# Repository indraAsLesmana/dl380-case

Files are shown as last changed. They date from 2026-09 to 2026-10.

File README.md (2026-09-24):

# DL380 Case — desktop enclosure for an HP ProLiant DL380 G6/G7 8-bay 2.5" SFF drive cage

Parametric [FreeCAD](https://www.freecad.org/) Python model of an external desktop
enclosure that turns a salvaged **HP ProLiant DL380 G6/G7 8-bay 2.5" SFF drive cage
with backplane** (cage assy P/N 496074-001 and relatives) into a standalone,
fan-cooled JBOD-style box with its own internal **PicoPSU**.

Everything — body, lid and PicoPSU strap — is generated from one script. Change a
number at the top, re-run, get a new STEP file. The rear section height is derived
from the fan, so swapping fan size re-shapes the enclosure by itself.

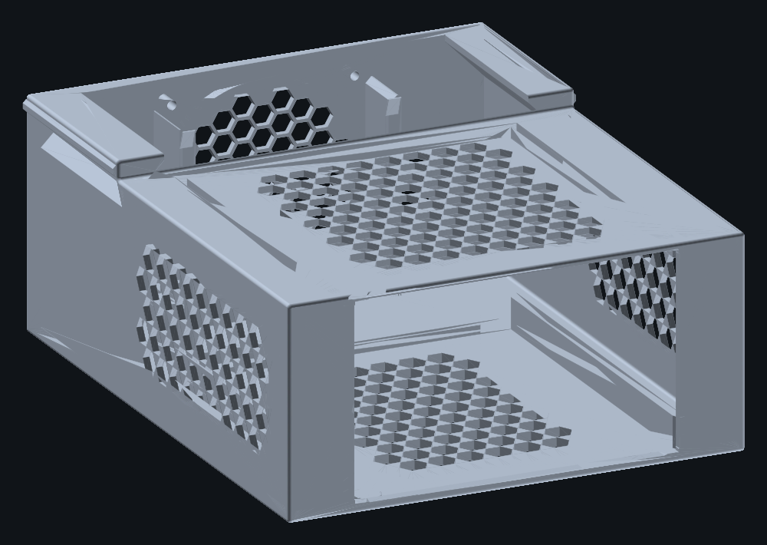
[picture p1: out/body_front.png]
front

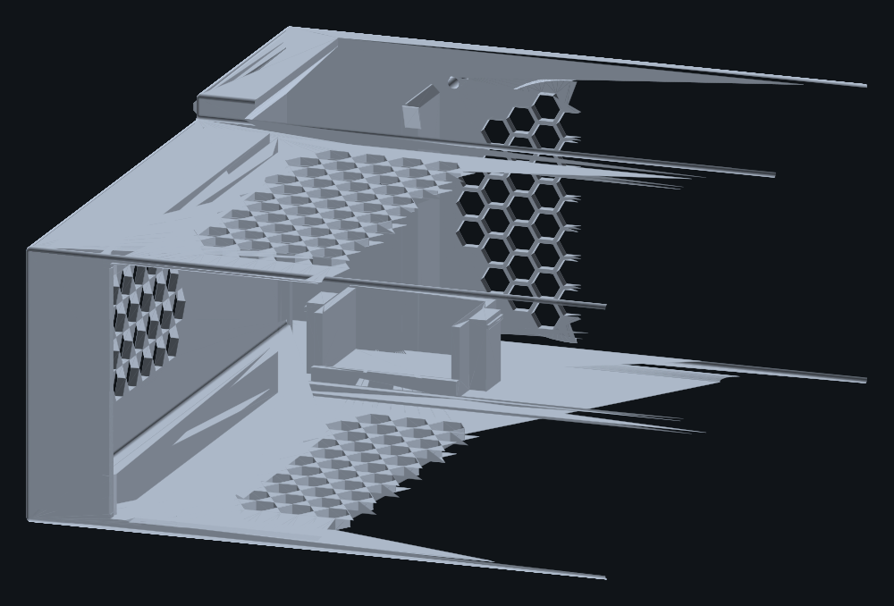
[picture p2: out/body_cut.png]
cutaway

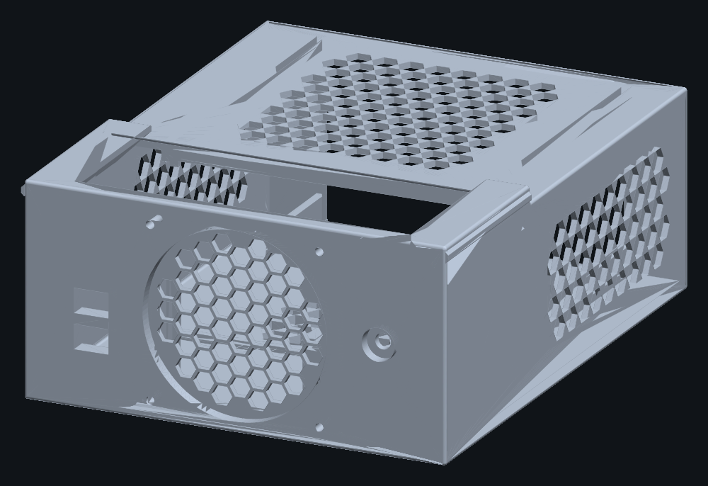
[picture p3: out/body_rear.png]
rear


**Building it? → [INSTALL.md](INSTALL.md)** — step-by-step assembly, including how
the drive cage goes in and the order the internals have to be fitted.

---

## Status

| | |
|---|---|
| Shell | `freecadcmd dl380_cage_case.py` builds and exports clean, no errors |
| Body solid | valid ✓ closed ✓ **208.40 × 102.80 × 253.40 mm** (572,008 mm³) — uniform 205.6 mm width & honeycomb net motif |
| Lid solid | valid ✓ closed ✓ **211.70 × 13.00 × 112.80 mm** (65,819 mm³) — slide-and-click with front pull ring |
| Strap solid | valid ✓ closed ✓ **69.20 × 10.00 × 14.00 mm** (4,267 mm³) — snap-fit |
| **Enclosure footprint** | **Uniform width**: 205.6 mm outer width throughout (bay & plenum), unbroken side walls; **253.4 mm depth** |
| **Drive bay net motif** | **258 hexagonal honeycomb cutouts (11 mm cell, 1.8 mm web)** on top, bottom, left & right walls — saves ~107 g solid (~80 g printed) |
| **Cage slide rails** | **Internal bottom slider rails (14 mm tall)** & **top guide ribs (5 mm tall)** with 1.5 mm lead-in chamfers |
| **Cable clearance** | **27.1 mm lateral space** to the left of the cage for side-facing 10-pin power plug & Wago blocks |
| **Lid retention** | **horizontal slide-and-click with front pull ring holder & compliant latch — 0 screws** |
| **PSU retention** | **toolless snap-fit strap with dual undercut retention teeth — 0 screws** |
| **Fan housing** | **Full-height 86 mm U-channel with front retaining rails (25.10 mm track depth)** — snug press-fit feel with zero screws |
| Body ↔ lid interference | **0.0000 mm³** (0.25 mm sliding clearance on 45° self-supporting rails) |
| Body ↔ strap interference | **0.0000 mm³** (0.20 mm snap clearance) |
| Cage slide path interference | **0.0000 mm³** (entrance to stop frame at Z = 162.0 mm) → CLEAR |
| PicoPSU phantom fit in the cradle | 0.0000 mm³ interference → CLEAR (transverse cradle shifted left X=-40.0 mm) |
| Build volume (Bambu Lab H2S / X1C) | **all parts fit on single 340×320 mm plate** (`print/dl380-case_all-parts.stl`, 331.2 × 253.4 mm layout) |
| Estimated print cost | **Rp 366,957 (~Rp 367,000)** for total enclosure at Rp 600/g PETG (612 g printed / 815 g solid) |
| Edge treatment | **every outer edge rounded** — body R1.4, lid R1.0, strap R1.4 |
| All parts printable | **100% support-free in native print orientations** ✓ |
| **Re-probed on the exported STEP** | `freecadcmd verify_step.py` → **71 probes, 0 failures** ✓ |

Reports: [`out/dl380_cage_case_report.txt`](out/dl380_cage_case_report.txt) is
written by the build; `verify_step.py` re-reads the exported STEP and probes the
body and the lid separately, with 71 probes confirming all geometries and clearances.

---

## Target hardware

The cage this was designed around, photographed on the bench:

| Photo | What it shows |
|---|---|
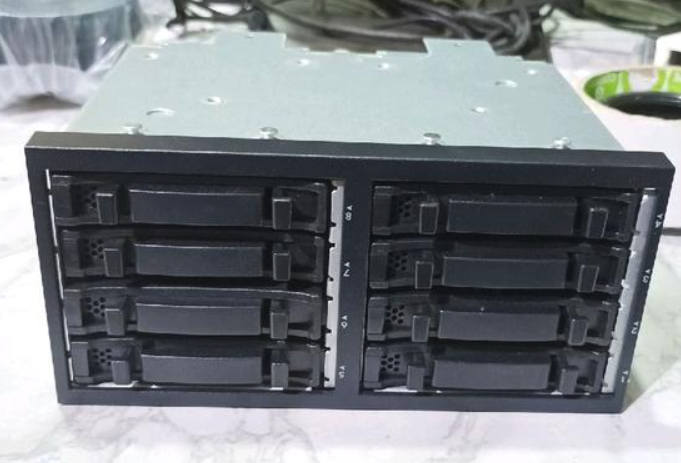
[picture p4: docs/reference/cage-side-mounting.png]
side
|  | Stamped steel cage, side/top mounting holes |
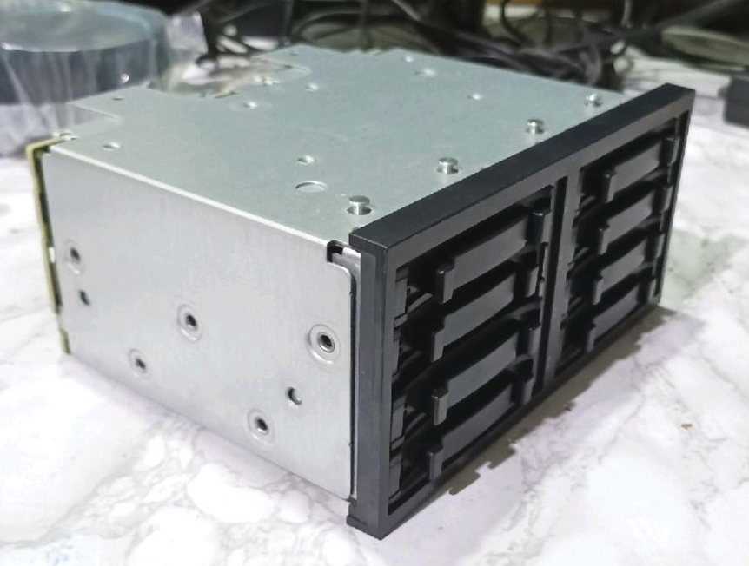
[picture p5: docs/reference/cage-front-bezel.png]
front
|  | Black plastic front bezel, 8 × 2.5" caddy slots |
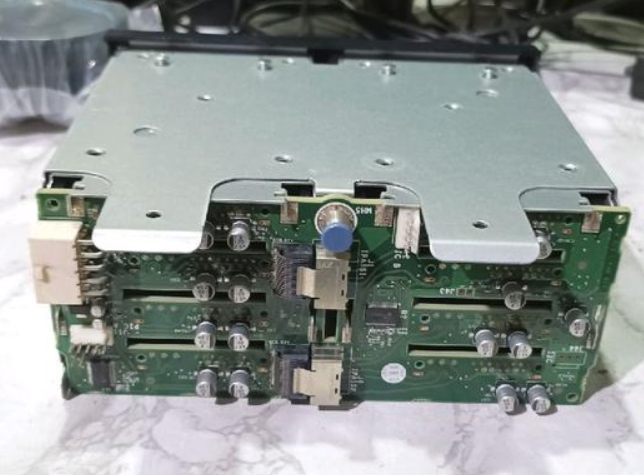
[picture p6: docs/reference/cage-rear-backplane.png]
backplane
|  | Backplane PCBs, left-facing 10-pin power socket, and top mounting rail |

Nominal cage envelope used for the model: **145.0 × 87.0 × 165.0 mm (W × H × D)**.

---

## Design

```
 z=0                                                               z=253.4
 | <---------- 165 bay ---------->|<-12->|<-- cradle -->|<-10.4->|<-25 fan->|<-8.4->|
 +================================+======+==============+========+==========+=======+ y=102.8
 | ^                              | boot |  PicoPSU     | cable  |   fan    |grille | STEP
 | |                              |      |  transverse  | space  |  INSIDE  | O90   | UP
 | | UNIFORM WIDE BODY (205.6 mm) |      |  X=+40 mm    |        |   92     | honey |
 | |                              |      |              |        |   frame  | comb  |
 | | [bottom rails + top ribs]    |      | [] |--board| |        |          |       |
 | |  capturing 145 mm cage       |      | [] | 44x31 | |        |  O86     |       |
 | | ### rear stop frame ###      |      |    |       | |        |  field   |       | y=0
 | v                              |      |    |-------| |        |          |       |
 +================================+======+==============+========+==========+=======+ y=94.6
 <------------------------------ 205.6 mm UNIFORM OUTER WIDTH ---------------------->
                                  <--------- 80 plenum ----------> (rear face)
   [] = strap bosses          all of the cradle and fan sits INSIDE the case
```

### Sections

**Bay (z 0 → 165)** — uniform outer width **205.6 mm** (matching the plenum for a clean,
monolithic profile with continuous side walls) and outer height 94.6 mm.
- **Front aperture**: 145.8 × 87.8 mm framed by 29.9 mm solid front cheeks on each side. The HP 2.5" SFF caddies and latch/eject levers slide straight in through the aperture, seating flush against the front face and sealing the front so that 100% of the exhaust fan's suction is pulled through the drive bays without bypass.
- **Internal slider rails**: 14 mm tall bottom guide rails on the floor and 5 mm tall ceiling ribs align and securely guide the 145 mm wide HP cage. A 1.5 mm 45° entry chamfer ensures the cage starts effortlessly.
- **Right wiring chamber**: Between the floor rails and ceiling ribs, a full **27.1 mm lateral clearance** on the right ($X = +72.9 \to +100.0\text{ mm}$) provides open routing space for the backplane's side-facing 10-pin power plug and harness.
- **Rear stop frame**: A 3 mm deep internal stop frame at $Z = 162 \to 165\text{ mm}$ sets the cage insertion depth; an inner aperture of 137.8 × 79.8 mm with a clearance notch on the lower-right edge ($X = +68.9 \to +72.9\text{ mm}$, $Y = 4 \to 50\text{ mm}$) guarantees zero fouling with the bottom-right backplane power port while leaving the left pillar solid from top to bottom.

**Plenum (z 165 → 245)** — **80 mm deep and 200 mm internal (205.6 mm outer)**.
The wide plenum gives **27.1 mm of lateral clearance** to the right of the backplane PCB,
providing ample room to plug in the 10-pin connector on the bottom right and execute a smooth bend toward the Wago lever blocks.
Laid out front to back:

| Z | What |
|---|---|
| 165 → 177 | 12 mm of clear boot space behind the backplane |
| 177 → 209.6 | the transverse PicoPSU cradle (shifted left to X = -40.0 mm) |
| 209.6 → 220 | 10.4 mm cable routing lane between cradle and fan |
| 220 → 245 | the fan, in its drop-in slot against the inside of the rear wall |

Shifting the PicoPSU to the left leaves a massive **117.2 mm of unobstructed plenum floor
on the right (X = -17.2 to +100.0 mm)** for the backplane power harness and three Wago 221
lever blocks.

**Fan — full-height U-channel housing with front retaining rails (snug press-fit feel).**
The ARCTIC P9 **slides straight down into a captive U-channel track** from the top and
seats on the plenum floor, exhausting straight through the grille. Nothing hangs off the
back of the enclosure and the blades are protected.

| | |
|---|---|
| Track | Z 219.90 → 245.00, providing an exact **25.10 mm track depth** for the 25.0 mm fan frame |
| Seat | the plenum floor (Y = 4.0 mm) — sets the height so screw holes line up if bolted |
| Sides (X) | two tall guide rails extending up to Y = 90.0 mm (`FAN_GUIDE_H = 86.0 mm`), 0.15 mm clearance per side, 2.5 mm lead-in chamfer |
| Forward (Z-) | **two tall front retaining rails** (Z 217.0 → 219.9 mm) overlapping the frame outer rim by 2.5 mm per side with top entry chamfers; completely clears the Ø86 mm blade circle |
| Behind (Z+) | the solid rear wall / grille face |
| Up (Y+) | **two fins on the lid's underside** reach down to 1 mm above the frame's top edge |

The full-height U-channel wraps the fan on all four vertical corners, providing a positive,
snug press-fit feel without requiring screws or rattling. With the lid closed, the fan is
completely locked in place in all 6 degrees of freedom.

Because the fan seats on the floor, its axis sits at **y = 50** rather than the
plenum's centre at 52, and the grille pocket and all four mounting holes moved down
2 mm with it.

**Drive bay net motif — weight & cost reduction cutouts.**
Instead of heavy solid plastic slabs around the drive bay, the top roof, bottom floor,
and left/right side walls feature an architectural **hexagonal honeycomb net motif**:
- **Geometry**: 258 hexagonal cells, **11.0 mm across flats** with **1.8 mm webs** (equivalent to 4–5 passes of a standard 0.4 mm nozzle for maximum rigidity and clean toolpaths).
- **Four-panel coverage**:
  - Top roof: 93 cells across a 120 × 134 mm field.
  - Bottom floor: 71 cells across a 90 × 122 mm field (clearing the rubber foot recesses).
  - Left and right side walls: 47 cells each across 134 × 68 mm fields.
- **Structural margins**: Solid perimeter borders are preserved at the front mouth ($Z < 16\text{ mm}$), the rear stop frame ($Z > 150\text{ mm}$), and along the floor rails and ceiling guide ribs.
- **Cost impact**: Saves **107 g of solid PETG (~80 g printed)** per enclosure, reducing filament cost and print time while facilitating passive air circulation.

**Honeycomb exhaust grille** — punched through a **3 mm membrane** at the bottom of
a Ø90 × 5.4 mm counterbore in the outer face, not through the full 8.4 mm wall, so
it costs little airflow and the wall stays stiff enough to carry the fan inserts.
55 flat-top hexagonal cells, 9 mm across flats with 1.2 mm webs, **78 % open** across
the field. The cell field is inset from the pocket wall so no cell can break out of
it; the tightest edge margin, pocket to case top edge, is **7.80 mm**.

**Rear wall (z 245 → 253.4)** — **8.4 mm** thick (3 × wall). Carries the grille, the
four fan mounting holes, two cable slots and the DC jack.

**Cable egress — out of the back.** Two 17 × 12 mm rounded slots at X = −70,
Y = 33 and 50 take the two SFF-8087 → SFF-8088 leads. Separate slots so each cable
keeps its own strain relief instead of two cables sawing against each other in one
hole. 16.50 mm from the slot corners to the grille pocket, 24.30 mm outboard.

**DC input jack** — Ø8 through, counterbored Ø16 × 5 mm on the outer face at
(+70, 52). The counterbore leaves a **3.4 mm panel** for the jack's nut
instead of the full 8.4 mm wall. 24.80 mm outboard margin.

**PicoPSU cradle** — see below.

**Lid — a slide-and-click housing that needs no screws.** The body is one cohesive
print with a closed top over the drive bay; the plenum gets a separable lid that
**slides horizontally forward along +Z** into interlocking rails on the body's outer
walls and clicks shut with a compliant snap latch.

| | |
|---|---|
| Guide rails | 45° beveled guide rails on outer walls (`RAIL_W = 1.4 mm`, `RAIL_H = 2.4 mm`), completely support-free |
| Skirt runners | 45° inverted runner grooves inside the lid skirts with `0.25 mm` sliding clearance |
| Snap latch | 18 mm compliant cantilever latch on the front face engaging a `20 × 2.6 × 1.8 mm` recessed catch pocket on the front vertical step |
| Catch tooth | 1.2 mm ramped catch tooth (`LATCH_TOOTH_D = 1.2 mm`) with ergonomic thumb-release tab |
| Pull ring holder | **Ø14 mm circular finger ring** (24 mm outer width, 22 mm projection) at front center for effortless removal |
| Located by | 45° interlocking rails in X and Y, front vertical step in -Z, snap tooth in +Z |
| Retained fan | fan captured on 4 sides by body U-channel; lid underside is flush over the fan with 4.0 mm clearance |
| Removed by | hooking index finger into the front pull ring and sliding the lid backward |

**100% screwless and toolless.** The interlocking 45° rails prevent the lid from lifting
up (+Y) or pulling outward in ±X. The front vertical step stops it from sliding too far
forward (+Z), and the latch tooth locks into the catch pocket to prevent it from sliding
backward (-Z).

**Roof gussets** — two **18 mm 45° gussets** run the length of the plenum roof/wall
corners. They make the roof printable without supports and provide rigid backing for
the slide rails.

**Base** — four Ø12 × 2 mm recesses for rubber feet, in a 4 mm floor.

**Edge treatment** — every outer edge is rounded: **R1.4** on the body and the PSU
strap, **R1.0** on the lid. Nothing on the outside is a sharp edge.

The rounds are applied to the **bare shell**, before anything is cut into it.
Filleting the finished body would also try to round the 1.2 mm honeycomb webs and
every internal corner, which OCC will not survive; and the coplanar faces have to be
merged first, or the seams between the two shell boxes get filleted into grooves.

R1.4 is close to the ceiling here: every outer edge sits on either a 2.8 mm wall or
a 3 mm lid plate, and the round has to leave a printable rim behind it.

**The cost, stated plainly**: the outer corner round and the cage lead-in flare both
remove material from the same 2.8 mm front wall, and at the mouth corner they add
up. Keeping the original 1.6 mm flare would have left **0.5 mm** there, so the flare
is reduced to 0.8 mm, which leaves exactly **1.00 mm**. So the cage's lead-in is
half what it was — see [INSTALL.md](INSTALL.md) step 2 for what that means in
practice.

### Why the rear section steps up 8.2 mm

A **92 mm fan frame is taller than the 87.8 mm cage bore**, so it cannot sit inside a
case only as tall as the bay. The rear section therefore steps from 94.6 mm to
102.8 mm — an 8.2 mm step, not the 37 mm tower an earlier revision had.

This is derived, not hand-set:

```python
INT_H_PLEN = max(INT_H, FAN_SIZE + 2*FAN_INNER_CLEAR)
REAR_H     = FLOOR_T + INT_H_PLEN + WALL     # 102.8 with a 92 mm fan
```

Give it a fan of **83.8 mm or less** and `REAR_H` collapses back to `BAY_H` and the
top becomes a flat prism. `FAN_SIZE` and `FAN_INNER_CLEAR` are the only numbers you
touch.

---

## Fitted fan — ARCTIC P9 PWM PST (ACFAN00298A)

Figures from ARCTIC's own spec sheet (`Spec_Sheet_P9_PWM_PST_EN.pdf`), not from a
reseller listing.

| | |
|---|---|
| Frame | 92 × 92 × 25 mm, 106 g |
| Mounting hole pattern | **82.5 × 82.5 mm** — matches `FAN_PATTERN` |
| Speed | 200–3000 rpm, PWM controlled (0 rpm below 5 % duty) |
| Airflow | 38.83 cfm / 65.97 m³/h |
| Static pressure | 3.12 mmH₂O — a high-pressure fan, which is what a caddy-stacked backplane wants |
| Bearing | fluid dynamic |
| Electrical | 12 V DC, 0.12 A = **1.44 W**, starts at 5 V |
| Lead | 400 mm + 80 mm PST daisy-chain, 4-pin plug **and** 4-pin socket |
| Ambient | 0–40 °C, 6 year warranty |

**Fit inside the enclosure**

| | |
|---|---|
| Bore it sits in | 200.0 × 96.0 × 80.0 mm |
| Frame clearance | 2.0 mm on every side |
| Fan position | Z 220 → 245, flat against the rear wall |
| Grille field | Ø90 pocket, Ø~86 of actual honeycomb |
| Mounting holes | Ø4.2 at (±41.25, 50 ± 41.25) — optional, the housing holds it |
| Housing | slot at Z 220→245, 0.2 mm per side, lid fins 1 mm above the frame top |

**Mounting** — with the housing, mounting is just "lower it in". The four M3 × 30
positions are still cut into the rear wall (heat-set inserts pressed in from the
**outside** face) if you would rather bolt it, in which case the screws go in from
inside the plenum. Point the fan so it exhausts outward and check the moulded
airflow arrow.

**Fan lead** — the 4-pin plug never leaves the case now, so no wall notch is needed.
Route the lead forward along the plenum and tuck it down before the lid goes on.

---

## PicoPSU cradle

Sized from mini-box's own figures for the **picoPSU-120: 31 × 44 × 21 mm (1U)**,
57 g with its harness, DC input a 5.5 × 2.5 × 10 mm barrel.

The board is **oriented transversely (44 mm across X, 31 mm along Z)** and shifted
right to **X = +40.0 mm** on the plenum floor. This leaves **117.2 mm of unobstructed
plenum floor on the left (X = -100.0 to +17.2 mm)** for the backplane power harness and
Wago 221 lever blocks.

| | |
|---|---|
| Cradle bore | 45.6 (across X) × 32.6 (along Z) mm (0.8 mm clearance per side) |
| Cradle Z | 177.0 → 209.6 mm |
| Mouth to backplane face | **12 mm** — board stops 13.6 mm short even fully forward |
| Plinth | 3 mm, so the solder side never touches the floor |
| Front lip | 6 mm tall (3 mm above the plinth) — stops it sliding forward |
| Retaining strap | 67.2 × 4 × 14 mm snap-fit strap with dual undercut teeth |
| Retention ledges | 0.8 mm retention ridges on the corner bosses — **no screws, no inserts** |

The build runs a **phantom PicoPSU box** through the cradle and reports the
interference (0.0000 mm³ → CLEAR).

**Two things to check on your own wiring**

1. The cradle holds the *bare board*. If you mount the 24-pin ATX connector facing
   up, it stands taller than the 21 mm board and the strap will be in the way. Either
   fit the strap around it, or change `PSU_BORE_Z` to move the strap along the cradle.
2. There is no motherboard here, so a PicoPSU will not start on its own — **PS_ON#
   must be tied to ground** for it to run as a standalone 12 V → 5 V/3.3 V supply.
   The fan's 1.44 W is nothing for the Wago 221 terminals, so it can share them.

---

## BOM

| Item | Qty | Notes |
|---|---|---|
| Printed body | 1 | ≈ 648 cm³ / ≈ 823 g at 1.27 g/cm³ (solid) |
| Printed lid (slide-and-click) | 1 | ≈ 66 cm³ / ≈ 83 g |
| Printed PSU strap (snap-fit) | 1 | ≈ 4.3 cm³ / ≈ 5 g |
| **ARCTIC P9 PWM PST 92 mm** | 1 | inside the plenum, exhaust; 106 g |
| **PicoPSU-120** (or similar) | 1 | 31 × 44 × 21 mm; add a 12 V brick + panel DC jack |
| Panel-mount 5.5 × 2.5 mm DC jack | 1 | Ø8 body, ≤ 3.4 mm panel |
| Rubber feet Ø12 × 2 mm | 4 | in base recesses |
| SFF-8087 → SFF-8088 cables | 2 | exit through the rear slots |
| Wago 221 lever terminals | 3 | in the plenum |
| **Mandatory screws / inserts** | **0** | **100% toolless assembly** |
| *Optional: M3 × 6 heat-set inserts* | *4* | *only if bolting the fan for transport* |
| *Optional: M3 × 30 screws* | *4* | *only if bolting the fan for transport* |
| *Optional: M3 screws + nuts* | *2–4* | *only if pinning the cage through side holes* |

### Print settings & Kit

PETG or ASA suggested (the plenum sees warm server air). 0.2 mm layers, 3–4 walls,
4–5 top/bottom layers. Total printed mass is **612 g** (815 g solid upper bound).
With the drive bay honeycomb net motif, the enclosure saves **107 g of solid PETG (~80 g printed)**!

### Cost Estimation @ Rp 600 / gram (PETG)

| Part | Volume (cm³) | Solid Mass (g) | Printed Mass (g) | Cost (Rp 600/g) |
|---|---|---|---|---|
| **Body** | 572.0 | 726 | 545 | Rp 326,902 |
| **Lid** | 65.8 | 84 | 63 | Rp 37,615 |
| **PSU Strap** | 4.3 | 5 | 4 | Rp 2,439 |
| **TOTAL** | **642.1** | **815** | **612** | **Rp 366,957** (~Rp 367,000) |

**No supports needed for any part**:
- The **body** prints upright on its base with the front opening facing up.
- The **lid** prints top-plate face down on the bed with skirts pointing up; the 45° runner overhangs are self-supporting.
- The **strap** prints flat on the bed.

A pre-arranged print kit is provided in `print/`:
- `print/dl380-case_all-parts.stl` / `.obj`: all 3 parts arranged on a single **331.2 × 253.4 mm plate** (fits within a 340 × 320 mm Bambu Lab build volume).
- Individual STLs: `dl380-case_body.stl`, `dl380-case_lid.stl`, `dl380-case_psu-strap.stl`.

---

## Rebuilding and verifying

```bash
# generate STEP + STL + report into ./out
freecadcmd dl380_cage_case.py

# export print-ready kit (individual + all-parts plate) into ./print
freecadcmd export_print_kit.py

# re-probe the exported STEP: every opening open, every wall solid
freecadcmd verify_step.py

# optional: dependency-free preview renders (SVG -> PNG via rsvg-convert)
python3 render_stl.py out/dl380_cage_case_body.stl out/body.png
python3 render_stl.py out/dl380_cage_case_lid.stl out/lid.png
python3 render_stl.py out/dl380_cage_case_strap.stl out/strap.png
```

Tested with FreeCAD 1.1.3 (`freecadcmd`). The scripts also run from the FreeCAD GUI
Python console via `exec(open("dl380_cage_case.py").read())`.

---

## Parameters

All at the top of `dl380_cage_case.py`. Nothing derived is hand-edited.

| Parameter | Default | Meaning |
|---|---|---|
| `CAGE_W` / `CAGE_H` / `CAGE_D` | 145.0 / 87.0 / 165.0 | HP cage envelope |
| `FIT_CLEAR` | 0.4 | slide-in clearance, per side |
| `WALL` / `FLOOR_T` | 2.8 / 4.0 | wall and floor thickness |
| `FILLET_R` / `FILLET_R_LID` | 1.4 / 1.0 | outer edge rounds, body+strap / lid |
| `LEAD_IN` / `LEAD_DEPTH` | 0.8 / 4.0 | cage lead-in flare — capped by the rounds |
| `SLIDE_CLEAR` | 0.25 | sliding clearance between body rails and lid runners |
| `RAIL_W` / `RAIL_H` / `RAIL_YC` | 1.4 / 2.4 / 98.0 | 45° slide rail width, height, and Y centerline |
| `LATCH_W` / `LATCH_TOOTH_H` / `LATCH_TOOTH_D` | 18.0 / 2.0 / 1.2 | snap latch width, tooth height, and undercut depth |
| `LID_RING_W` / `LID_RING_LEN` / `LID_RING_HOLE` | 24.0 / 22.0 / 14.0 | front pull ring width, projection, and finger hole Ø |
| `PSU_SNAP_CLEAR` / `PSU_LEG_T` / `PSU_TOOTH_W` | 0.2 / 2.0 / 0.8 | snap-fit strap clearance, leg thickness, and retention tooth |
| `REAR_WALL_LAYERS` | 3 | rear wall in wall-units → 8.4 mm |
| `GUSSET_H` | 18.0 | 45° roof gusset size (sets the service opening width) |
| `PLENUM_D` | 80.0 | clear depth behind the backplane |
| `FAN_SIZE` / `FAN_INNER_CLEAR` | 92.0 / 2.0 | frame size and bore clearance |
| `FAN_APERTURE` / `FAN_PATTERN` / `FAN_HOLE` | 86.0 / 82.5 / 4.2 | grille field and mounting pattern |
| `FAN_INSET` | 25.0 | fan depth against the rear wall |
| `FAN_GUIDE_CLEAR` | 0.15 | clearance per side in the fan housing |
| `FAN_GUIDE_T` / `FAN_GUIDE_H` / `FAN_GUIDE_CHAM` | 3.0 / 86.0 / 2.5 | rail thickness, height, lead-in |
| `FAN_FRONT_Z_IN` / `FAN_FRONT_X_IN` | 219.90 / 43.50 | front retaining rail boundary (25.10 mm track depth) |
| `NET_CELL` / `NET_WEB` | 11.0 / 1.8 | drive bay honeycomb net cell and web size |
| `GRILLE_CELL` / `GRILLE_WEB` | 9.0 / 1.2 | rear exhaust grille honeycomb cell and web size |
| `GRILLE_RIM` / `GRILLE_DEPTH` | 2.0 / 3.0 | solid rim, membrane thickness |
| `PSU_W` / `PSU_L` / `PSU_H` | 31 / 44 / 21 | the board envelope |
| `PSU_CX` | 40.0 | cradle center offset along X (leaves 117 mm cable floor on left) |
| `PSU_CLEAR` / `PSU_BOOT` / `PSU_PLINTH_T` | 0.8 / 12.0 / 3.0 | fit, backplane gap, plinth |
| `PSU_WALL_H` / `PSU_FRONT_LIP` | 24.0 / 6.0 | cradle wall and lip heights |
| `PSU_BORE_Z` | 193.3 | strap position along the cradle |
| `REAR_CABLE_SLOT_*` | X −70, Y 33/50, 17 × 12 | rear cable egress |
| `DC_JACK_X` / `DC_JACK_Y` | 70.0 / 52.0 | DC jack position |
| `DC_JACK_DIA` / `DC_JACK_PAD` / `DC_JACK_DEPTH` | 8.0 / 16.0 / 5.0 | jack hole and counterbore |
| `CAGE_SCREW_Z` | 15…155 | candidate cage anchor positions |
| `REAR_H` | *derived* | follows the fan automatically |

---

## Caveats — read before printing

1. **Cage side-screw positions are unverified.** `CAGE_SCREW_Z` places six Ø3.4 holes
   per side wall as a *menu*, not a measurement — the real cage's own holes were not
   measured. The rear stop frame holds the cage regardless.
2. **The PicoPSU cradle is sized for the bare picoPSU-120 (31 × 44 × 21 mm).** Check
   your board before printing; other PicoPSU models differ, and `PSU_W/L/H` and
   `PSU_BORE_Z` are the numbers to change.
3. **The DC jack counterbore leaves a 3.4 mm panel.** Measure your jack's neck and
   change `DC_JACK_PAD` / `DC_JACK_DEPTH` if it wants something different.
4. **Rear section is 8.2 mm taller than the bay.** That is what an internal 92 mm fan
   costs. Use an 83.8 mm-or-smaller fan and the top is flat again.
5. **Dimensions are from the brief, not from calipers.** If your cage measures
   differently, change `CAGE_W` / `CAGE_H` / `CAGE_D` and rebuild.
7. **Nothing here has been printed yet.** The geometry is verified as valid, closed,
   non-interfering, phantom-fitted and feature-by-feature against the exported STEP,
   but that is not the same as a successful print.

---

## Repository layout

```
dl380_cage_case.py            parametric model -> STEP/STL (the thing to edit)
verify_step.py                re-probes the exported STEP; non-zero exit on failure
render_stl.py                 standalone STL -> shaded PNG renderer
docs/reference/               photos of the target hardware
out/
  dl380_cage_case.step        body + lid + strap, high precision  <- deliverable
  dl380_cage_case_body.step   body only
  dl380_cage_case_lid.step    lid only
  dl380_cage_case_strap.step  PicoPSU strap only
  dl380_cage_case_*.stl       print meshes
  dl380_cage_case_report.txt  derived dimensions + sanity checks
  *.png                       preview renders
```

---

## License

MIT — see [LICENSE](LICENSE).

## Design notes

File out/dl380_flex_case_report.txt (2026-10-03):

================================================================================
DL380 MODULAR 2-PIECE FLEX-ATX ENCLOSURE - BUILD & COMPARISON REPORT
================================================================================

Target Cage:      HP ProLiant DL380 G6/G7 8-bay 2.5" SFF (144.81 x 75.52 x 137.25 mm)
Target PSU:       Enhance ENP-2320 (Flex-ATX 200W, 150 x 81.5 x 40.5 mm)
Target Fan:       92 mm Arctic P9 PWM PST / Noctua NF-A9 (92 x 92 x 25 mm)

VARIANT 1: STANDARD (CAD Built-in DfAM Sacrificial Supports)
  Front Case Vol: 893,933.96 mm3 (isClosed: True) | Facets: 10,866
  Back Case Vol:  600,264.80 mm3 (isClosed: True) | Facets: 6,310
  Service Lid Vol:21,875.90 mm3 (isClosed: True) | Facets: 300
  Total Volume:   1,516,074.66 mm3 (1,516.1 cm3)

VARIANT 2: CLEAN (Zero CAD Supports - Ready for Slicer Auto-Support Comparison)
  Front Case Vol: 778,782.94 mm3 (isClosed: True) | Facets: 2,282
  Back Case Vol:  553,984.83 mm3 (isClosed: True) | Facets: 2,082
  Total Volume:   1,354,643.67 mm3 (1,354.6 cm3)
  CAD Support Material Delta: 161.4 cm3 (~203.4 g PETG)

================================================================================

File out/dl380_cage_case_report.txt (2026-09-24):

==============================================================================
 DL380 G6/G7 8x2.5" SFF drive-cage desktop enclosure - build report
==============================================================================

 TARGET HARDWARE
   cage outer              : 145.0 x 87.0 x 165.0 mm (W x H x D)
   sleeve bore             : 145.8 x 87.8 mm  (0.4 mm/side clearance)

 ENCLOSURE  (body)
   outside W x H x D       : 205.6 (uniform) x 102.8 x 253.4 mm
   bay section             : 205.6 (W) x 94.6 (H) x 165.0 (D) mm
   fan/plenum section      : 205.6 (W) x 102.8 (H) x 88.4 (D) mm
   top profile             : STEPPED - rear section is 8.2 mm taller than the bay (fan is inside)
   wall / floor / rear wall: 2.8 / 4.0 / 8.4 mm
   plenum clear depth      : 80.0 mm
   roof gussets            : 18.0 mm tall at 45 deg, carrying the lid rails

 HP CAGE SLIDER RAILS & GUIDE RIBS  (internal)
   bottom guide rails      : 14.0 mm tall x 4.0 mm thick on floor (Z 2.8..165.0)
   top guide ribs          : 5.0 mm tall x 4.0 mm thick on roof (Z 2.8..165.0)
   front mouth lead-in     : 1.5 mm 45 deg chamfer at entry (Z=2.8..5.8)
   lateral wiring clearance: 23.1 mm open side chamber on right for 10-pin harness

 FAN  -  ARCTIC P9 PWM PST  (ACFAN00298A)
   nominal size            : 92 x 92 x 25 mm, 106 g
   P9 PWM PST rating       : 200-3000 rpm PWM (0 rpm below 5%),
                             38.83 cfm | 65.97 m3/h, 3.12 mmH2O static,
                             0.12 A @ 12 V = 1.44 W, fluid dynamic bearing
   position                : in a slot against the rear wall, Z 220.0..245.0,
                             seated on the plenum floor
   fan axis                : (0, 50.0) - the frame sits ON the floor at
                             y=4.0, so the axis is 2.0 mm below the
                             centre of the plenum bore
   hole pattern            : 82.5 x 82.5 square, O4.2
   hole centres (X,Y)      : (+/-41.2, 8.8)  (+/-41.2, 91.2)

 FAN HOUSING  - tall U-channel with front retaining rail (press-fit feel)
   how it goes in          : straight DOWN into the U-channel at Z 220.0..245.0
   seat                    : the plenum floor.  This sets the height, so
                             the screw holes line up if you ever use them
   sides (X)               : two tall guide rails 86.0 mm up from the floor (y=90.0),
                             0.15 mm clearance per side, 2.5 mm lead-in
   behind (Z+)             : the rear wall / grille face at Z=245.0
   forward (Z-)            : two tall front retaining rails (Z=217.0..219.9),
                             overlapping fan frame by 2.5 mm per side with 2.5 mm entry chamfer
   track depth (Z)         : 25.10 mm (for 25.0 mm fan frame) -> snug press-fit feel
   up (Y+)                 : closed by lid plate (4.0 mm headroom above frame)
   => restrained on all six sides: toolless slide-in, zero screws, rock solid

 DRIVE BAY NET MOTIF  (weight & cost reduction cutouts)
   pattern                 : hexagonal honeycomb mesh (11.0 mm cells, 1.8 mm webs)
   cutout panels           : top roof, bottom floor, left wall, right wall
   total hex cells         : 258 cells
   cost impact             : reduces raw plastic mass by ~107 g solid (~80 g printed)

 HONEYCOMB EXHAUST GRILLE  (recessed into the outer face)
   pocket                  : O90.0, 5.4 mm deep
   membrane                : 3.0 mm thick
   cell / web              : 9.0 mm across flats / 1.2 mm walls
   cells                   : 55
   open fraction of field  : 78%
   tightest edge margin    : 7.80 mm (pocket to the top edge)

 PicoPSU CRADLE  (transverse, shifted left X=-40.0 mm)
   board                   : 44.0 (L, across X) x 31.0 (W, along Z) x 21.0 (H) mm
   cradle inner            : 45.6 x 32.6 mm, 0.8 mm clearance per side
   cradle Z                : 177.0 .. 209.6  (mouth to rear wall)
   backplane clearance     : 12.0 mm from the cradle mouth to the
                             backplane face - the board cannot reach it
   lateral clearance       : 117.2 mm open plenum floor on right (X=-17.2..100.0)
                             for backplane power cable and Wago 221 lever blocks
   plinth                  : 3.0 mm, board sits clear of the floor
   front lip               : 6.0 mm tall (3.0 mm above the plinth),
                             stops the board sliding forward
   retaining strap         : 67.2 x 4.0 x 14.0 mm, toolless snap fit
                             clips over corner boss ledges (0 screws, 0 inserts),
                             0.4 mm gap over the board top

 DC INPUT JACK  (rear wall)
   centre                  : (-70.0, 52.0)
   panel counterbore       : O16.0 x 5.0 mm deep, leaving a 3.4 mm
                             thick panel for the jack nut
   jack hole               : O8.0 through
   edge margin             : 164.80 mm outboard

 CABLE EGRESS  (rear wall, beside the grille)
   2 slots                : 17.0 (X) x 12.0 (Y) mm, rounded corners
   centres                 : X=+70.0   Y = 33.0, 50.0
   fitted SFF-8088 lead    : ~12.5 x 8 mm, so 4.5 x 4.0 mm of slack
   clearance to the grille : 16.50 mm (slot corner to the pocket)
   clearance to the edge   : 24.30 mm outboard

 SERVICE LID  (slide-and-click housing - 100% screwless)
   outside                 : 211.7 (W) x 90.8 (D) mm, 3.0 mm plate
   skirts                  : 10.0 mm deep at the sides, 6.4 mm
                             at the front (covering the step), all 2.8 mm thick
   guide rails             : 45 deg beveled slide rails on outer walls (Z 166.5..253.4)
                             glide clearance: 0.25 mm
   cantilever latch        : 18.0 mm wide spring arm with 1.2 mm catch tooth
   pull ring holder        : O14.0 mm finger hole at front center for effortless removal
   positive stop           : front face seats against 8.2 mm step at Z=165.0
   screws                  : 0 (100% toolless slide-and-click)

   FAN CABLE & RETENTION   - fan captive with no screws
   fan underside clearance : flush lid underside, fan captured in body U-channel
   headroom over the frame : 4.0 mm (frame top y=96.0, ceiling y=100.0)
   skirt vs the case       : the skirt is outside the case, so it cannot
                             reach any cable that is inside

   service opening         : 164.0 wide, Z 165.0..245.0, R12.0 corners
   entry for the fan       : Z 220.0..245.0, straight down into the housing.
                             The front tabs and rails make that the only
                             way in, so there is nothing to slide or align
   roof left beside opening: 18.0 mm each side, plus 0.0 mm across
                             the front

 EDGE TREATMENT  (outside edges only, for handling and to stop chipping)
   body / strap fillet     : R1.4 on every outer edge
   lid fillet              : R1.0 (its plate is only 3.0 mm thick)
   filleted                : yes
   material the rounds took : 941 mm3 off the bare shell
   wall at the mouth corner : 1.00 mm  (2.8 wall - R1.4 - 0.4 lead-in)
   lead-in flare           : 0.8 mm total, down from 1.6 mm - the round
                             and the flare both cut the same 2.8 mm
                             front wall, so one had to give

 VOLUME / MASS / PRICING @ Rp 600/g
   body   volume / solid / prn:   572.0 cm3 |   727 g (solid) |   545 g (printed) -> Rp    326926
   lid    volume / solid / prn:    65.8 cm3 |    84 g (solid) |    63 g (printed) -> Rp     37615
   strap  volume / solid / prn:     4.3 cm3 |     5 g (solid) |     4 g (printed) -> Rp      2439
   ----------------------------------------------------------------------------------
   TOTAL ENCLOSURE          :   642.1 cm3 |   816 g (solid) |   612 g (printed) -> Rp    366981

 SANITY CHECKS
   body valid              : True
   lid valid               : True
   strap valid             : True
   body closed (solid)     : True
   strap closed (solid)    : True
   body bbox               : 208.40 x 102.80 x 253.40
   lid  bbox               : 211.70 x 13.00 x 112.80
   body/lid interference    : 0.0000 mm3
   body/strap interference  : 0.0000 mm3
   build volume (Bambu H2S 340x320x340):
     body  fits            : True
     lid   fits            : True
     strap fits            : True
   PicoPSU phantom fit (board pushed to the rear of the cradle):
     board/body interference: 0.0000 mm3  -> CLEAR
     board front to backplane: 13.60 mm in the rearmost position
   HP cage slide path (145.0 x 87.0 mm, entrance to stop frame at Z=162.0):
     cage/body interference  : 0.0000 mm3  -> CLEAR
   slide rails on body     : length 86.9 mm (Z 166.5..253.4), height 95.4..100.6 mm
   front catch pocket      : 20.0 (W) x 2.6 (H) x 1.8 (D) mm at Z=165.0
   cable egress slots through the rear wall:
     X= +70.0 Y= 33.0 : 0% inside solid  -> CLEAR
     X= +70.0 Y= 50.0 : 0% inside solid  -> CLEAR

 NOTES
   * The 92 mm fan frame is taller than the 87.8 mm bay bore, so the
     rear section steps up 8.2 mm to hold it inside.
     The largest fan that would keep the top flat is 83.8 mm.
   * Air path: open front -> caddies -> plenum -> fan -> honeycomb grille.
     No tapered duct any more: with the fan inside the plenum there is
     nothing to funnel into, and the volume is needed for cabling.
   * The grille is punched through a 3.0 mm membrane, not the full 8.4 mm
     wall, so it costs little airflow and still looks clean.
   * Cage side-screw Z positions are a starting suggestion: drill/print
     only the pair that lines up with your cage's own holes.
   * Rear stop frame inner aperture: 137.8 x 79.8 mm
==============================================================================

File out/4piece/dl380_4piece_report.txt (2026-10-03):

================================================================================
DL380 4-PIECE MODULAR ENCLOSURE - BUILD REPORT
================================================================================

Part 01A (Lower Front): 173,420.24 mm3 (isClosed: True)
Part 01B (Upper Front): 634,305.48 mm3 (isClosed: True)
Part 02A (Lower Back):  109,494.95 mm3 (isClosed: True)
Part 02B (Upper Back):  427,795.79 mm3 (isClosed: True)
Part 03  (Service Lid): 21,891.54 mm3 (isClosed: True)
Part 04  (Cage Pin x1): 224.84 mm3 (isClosed: True)
Total Volume:           1,367,357.67 mm3 (1,367.4 cm3, ~1,722.9 g PETG)
================================================================================

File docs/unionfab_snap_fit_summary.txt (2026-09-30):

Title: Cached Content
Description: Fetched from cache
Source: https://www.unionfab.com/blog/2025/06/3d-print-snap-fit
---
Guide to 3D Printed Snap Fits +[Design Tips]
Guide to 3D Printed Snap Fits +[Design Tips]
Allen Yang
About
12
mins
Published:
June 4, 2025
Design tool-free 3D printed snap-fit joints for fast, durable assembly—explore TPU, Nylon, PETG, and expert FDM/SLS tips for real-world applications.
Introduction
What is a Snap-Fit?
A snap-fit is a type of mechanical joint that enables quick assembly and disassembly using elastic deformation. It eliminates the need for screws, adhesives, or other fasteners. Widely used in electronics, consumer products, and modular components, snap-fit joints are especially well-suited for 3D printing due to their cost-effectiveness and ease of fabrication.
Common Snap-Fit Types
Cantilever (Most Common, Single-Sided Insertion)
A single flexible arm that locks into place with a one-sided insertion. Subtypes include:
source: hp.com
Straight Cantilever:
A simple straight arm with a hook or tab at the end (e.g., used in food container lids for easy locking).
L-shaped Cantilever:
Features a right-angle bend, ideal for compact spaces (e.g., latches in electronics enclosures).
U-shaped Cantilever:
Two parallel arms forming a U-shape, offering balanced flexibility (e.g., in medical device casings).
Annular (Ring Structure)
Annular Snap Fit and Its Assembly Operation
Source: hp.com
A circular snap fit that uses radial flexibility (expansion/contraction) to lock, such as bottle caps, jar lids, or pipe fittings.
Torsional
Torsional Snap-fit and Its Assembly Operation
Source: hp.com
Engages through rotational deformation, requiring a twisting motion to lock (e.g., hose couplings or electrical plugs).
Latching
Snap Fit Plastic Push Latch
Source: pingood.com.tw
Two separate components (a hook and a slot) that interlock and can be manually unlocked, like safety harnesses or smartphone back covers.
Snap Fit Manufacturing Processes
Manufacturing Process
Suitability for Snap Fits
Description
3D Printing
Highly Suitable
Ideal for rapid prototyping, custom designs, and low-volume production. Enables quick design iteration with flexible materials like TPU/Nylon.
Injection Molding
Most Common
The standard for high-volume production, especially for plastic parts (e.g., electronics casings, toys). Offers cost efficiency at scale.
CNC Machining
Limited
Poorly suited for flexible components (metals/hard materials lack elasticity). Best for rigid prototypes with simple geometries.
Silicone Molding + Casting
Feasible for Low-Volume
Used to produce small batches of flexible snap fits (e.g., resin-cast clips) with moderate precision and flexibility.
Key Takeaway:
3D printing is the most versatile for snap fits, especially in early design stages. It allows rapid testing of locking mechanisms, easy modification of flexible arms/hooks, and supports materials that mimic production-grade elasticity.
3D Printing Processes for Snap Fits
1. Fused Deposition Modeling (FDM/FFF)
How it works:
Melts thermoplastic filaments (e.g., PLA, PETG, TPU) and deposits them layer by layer to build parts.
Why it’s ideal:
Flexibility: Supports elastic materials (e.g., TPU) for bendable cantilever arms or torsion springs.
Speed: Rapid turnaround for prototyping, allowing same-day design iterations.
Cost: Affordable for small batches or one-off custom designs.
2. Multi Jet Fusion (MJF) / Selective Laser Sintering (SLS)
How it works:
MJF: Fuses fine nylon powder (e.g., PA12, PA11) using a fusing agent and infrared energy.
SLS: Sintering nylon powder with a high-powered laser in a powder bed.
Why they’re ideal for snap fits:
Material Strength: Nylon parts have high tensile strength and fatigue resistance—ideal for repeated snap actions.
Elastic Recovery: PA11 and PA12 exhibit excellent shape memory, supporting tight tolerances without permanent deformation.
Isotropic Properties: Near-uniform strength in all directions—critical for flexible arms or latches.
No Support Structures: Enables printing of complex or nested snap geometries.
Surface Finish: MJF offers better detail and consistency; SLS is slightly rougher but similarly strong.
Want to bring your snap fit model to life? Choose Unionfab—your professional 3D printing partner for fast, reliable results from concept to production!
Sign Up to Get 10% Discount
Material Selection
Selecting the right material is critical to achieving durable, functional, and reusable snap-fit mechanisms. The ideal material must withstand stress concentrations, flex repeatedly without fatigue, and provide consistent shape recovery after deflection.
1. Key Material Requirements
Flexibility
The material should bend without cracking, especially in cantilever or living hinge designs where repeated deflection is expected.
Elastic Recovery
It must return to its original shape after deformation to ensure a secure, reusable snap-fit engagement.
Fatigue Resistance
The material should withstand repeated cycles of stress without permanent deformation or failure.
Layer Adhesion
In 3D printing, strong inter-layer bonding is crucial to prevent delamination, especially in parts subjected to flexing or bending.
Printability
Materials should offer good dimensional accuracy, surface quality, and consistency to meet tight snap-fit tolerances.
Impact Strength
Important for applications where snap-fits may experience sudden forces during assembly or in use.
2.  Recommended Materials for Snap-Fit Manufacturing
Material
Flexibility
Elastic Recovery
Fatigue Resistance
Layer Adhesion
Printability
Impact Strength
Nylon (PA12/11)
⭐
⭐
⭐
⭐
⭐
⭐
☆*
⭐
⭐
⭐
⭐
⭐
⭐
⭐
⭐
☆
⭐
⭐
☆
⭐
⭐
⭐
☆
PETG
⭐
⭐
☆
⭐
⭐
☆
⭐
⭐
☆
⭐
⭐
⭐
☆
⭐
⭐
⭐
☆
⭐
⭐
⭐
☆
ABS
⭐
⭐
☆
⭐
⭐
☆
⭐
⭐
☆
⭐
⭐
☆
⭐
⭐
☆
⭐
⭐
⭐
☆
PLA
⭐
☆
⭐
☆
⭐
☆
⭐
⭐
⭐
☆
⭐
⭐
⭐
⭐
⭐
⭐
⭐
☆
TPU
⭐
⭐
⭐
⭐
⭐
⭐
⭐
⭐
⭐
⭐
⭐
⭐
⭐
⭐
☆
⭐
⭐
⭐
☆
⭐
⭐
⭐
☆
⭐
⭐
⭐
☆
ASA
⭐
⭐
☆
⭐
⭐
☆
⭐
⭐
⭐
☆
⭐
⭐
⭐
☆
⭐
⭐
☆
⭐
⭐
⭐
☆
PC (Polycarbonate)
⭐
⭐
⭐
☆
⭐
⭐
⭐
☆
⭐
⭐
⭐
☆
⭐
⭐
☆
⭐
☆
⭐
⭐
⭐
⭐
⭐
*Note: ☆=1/2
⭐
3. Material Selection Tips by Use Case
Snap-fit components come in many forms, but they can all be grouped according to their functional scenarios. Below is a breakdown of typical snap-fit use cases, along with recommended 3D printing materials tailored to the performance requirements of each application.
High-cycle snap-fit clips
Recommended Materials: Nylon, TPU
Reason: Offer superior fatigue resistance and flexibility, enabling them to withstand frequent opening and closing operations without easily getting damaged.
General-purpose parts
Recommended Materials: PETG, ABS
Reason: Strike a good balance between durability and printability. They can meet the strength requirements of general usage scenarios while being easy to 3D print.
Outdoor use
Recommended Materials: ASA, PETG
Reason: Possess excellent UV and weather resistance, allowing them to be used outdoors for long periods without aging rapidly.
Prototyping / low-stress fits
Recommended Materials: PLA+, Tough PLA
Reason: Easy to print and have a fast printing speed, enabling the rapid production of prototypes. Suitable for assembly scenarios with low stress.
Flexible / soft interfaces
Recommended Material: TPU
Reason: Have high elasticity, providing a comfortable touch. Ideal for applications requiring soft and deformable interfaces.
Structural or heat-tolerant parts
Recommended Materials: PC, Nylon
Reason: Feature high strength and good thermal resistance, meeting the manufacturing requirements of parts with demands for structural strength and high-temperature tolerance.
Still unsure which material to choose? Talk to Unionfab experts to help you make final decisions.
Talk to Unionfab Experts
Snap-Fit Design Guidelines
Designing effective snap-fit components in 3D printing requires balancing flexibility, strength, and dimensional accuracy. This guide covers geometry considerations, and tolerance strategies to ensure durable and functional snap mechanisms.
Dimensions & Tolerances
These geometric rules help you design snap-fits that function reliably, even under repeated use and varying print conditions.
Clearance / Gap Tolerance
Recommended: 0.2–0.5 mm, depending on the printer's dimensional accuracy and material shrinkage.
Purpose: Prevents parts from fusing or being too tight.
Adjustment: For softer or more flexible materials (e.g., PETG, TPU), tighter clearances (~0.2 mm) may work. For stiffer materials or less accurate printers, go closer to 0.5 mm.
Arm Length
Rule of thumb: 2–3× the arm thickness.
Effect: Longer arms provide greater flexibility and easier snap engagement but may be more prone to fatigue. Shorter arms are stiffer but more durable.
Design Note: Keep a consistent cross-section and avoid sudden thickness changes to reduce stress concentration.
Hook Angle
Insertion Angle: 30°–45° recommended.
Explanation:
Lower angles (30°): Easier to insert, but weaker holding force.
Higher angles (45°+): Greater retention, but harder to engage or disengage.
Tip: Consider using asymmetrical hooks—shallow angle for insertion side, steeper on the locking side.
Fillets and Radii
Why: Sharp corners at the base of the snap arm act as stress risers and can lead to failure during flexing.
Suggestion:
Add fillets with radius = 0.5–1.0× arm thickness at the base of snap arms.
Smooth transitions between hook, arm, and base improve durability.
Lead-in Angles / Chamfers
Purpose: Chamfers or tapered entries guide the snap feature into place during assembly.
Angle Range: 20°–30° lead-in on hooks and mating surfaces is ideal.
Design Bonus: Improves user experience by reducing required insertion force and misalignment risk.
Undercuts & Retention Geometry
For strong locking, integrate subtle undercuts or stepped grooves—but avoid excessive interference which can cause cracking.
Use slicer preview to verify printability of undercut features or consider using breakaway supports if needed.
Material-Specific Notes
PLA: Brittle; suitable for one-time snaps or non-critical features.
PETG: Good balance of strength and flexibility; ideal for reusable snap-fits.
ABS/ASA: Tough, weather-resistant; great for functional outdoor parts.
Nylon: Excellent fatigue resistance; best choice for high-cycle snapping.
TPU: Highly flexible; useful for interference fits or soft latching mechanisms.
Testing & Iteration Tips
Prototype quickly using draft print settings to verify tolerances and clearances.
Print in intended orientation and test snap-fit behavior in real-world conditions.
Use modifier meshes to increase infill only in snap regions for strength without wasting material.
Printing Parameters & Orientation
Choosing the right print settings and orientation is crucial for strong, functional, and reliable snap-fit components. Below are detailed recommendations to help optimize strength, flexibility, and print quality.
Layer Height
Recommended: 0.1–0.2 mm
Why it matters:
Smaller layer heights (e.g., 0.1 mm) give finer detail and smoother surfaces, ideal for tight-fitting snap features.
Larger layer heights (e.g., 0.2 mm) print faster but may create rougher surfaces and weaker layer adhesion.
Tip:
For precision snap-fits or parts that require frequent engagement, use ≤ 0.15 mm for better dimensional accuracy.
Wall/Perimeter Thickness
Recommended: ≥ 1.2 mm (3 or more perimeters)
Why it matters:
Thicker walls increase strength in flexible arms and hook regions.
Critical for preventing cracks at stress points, especially in cantilever snap joints.
Tip:
Use 3–4 wall lines, or wall thickness = 3× nozzle diameter (e.g., 0.4 mm nozzle → 1.2 mm wall).
Printing Temperature
Why it matters:
Correct extrusion temperature ensures strong inter-layer adhesion. Too low = weak layers, too high = stringing or deformation.
Material
Nozzle Temp
Bed Temp
Notes
PLA
190–210°C
50–60°C
Keep cooling fan on for crisp detail
PETG
230–250°C
70–90°C
Reduce fan speed to strengthen layers
ABS
230–250°C
90–110°C
Enclosure recommended to reduce warping
ASA
240–260°C
90–110°C
Good ventilation needed for fumes
Nylon
240–260°C
70–90°C
Must dry before printing to avoid bubbling
Print Orientation
Goal: Maximize snap-fit durability and avoid layer separation under stress.
Best Practices:
Align flex direction parallel to the layers (XY plane): This ensures the part bends across layers, not between them.
Avoid printing snap arms upright (Z-axis) — they are more likely to break at the layer lines.
Examples:
For a U-shaped snap: lay the part flat so the arms extend in the XY direction.
For a cantilever hook: orient the hook horizontally to align its base along the layers.
Support Settings
Why it matters:
Snap-fits often include overhangs and hooks that require support. Improper support can damage delicate features or make post-processing difficult.
Recommendations:
Enable support only where needed.
Use “touching buildplate only” or support blockers to avoid internal cavities getting filled.
Design with 45° overhangs where possible to eliminate the need for supports.
Post-Processing Tips
1. Deburring and Cleaning
Purpose:
Remove stringing, rough edges, or blobs to ensure smooth snapping.How to do it:
Use a hobby knife or small file to clean up hooks and slots.
Focus on key contact areas where parts engage.
Note:
Avoid removing too much material—this may affect fit.
2. Sanding and Smoothing
Purpose:
Improve surface finish and reduce friction between snap parts.How to do it:
Sand with 400–1000 grit sandpaper for a smoother surface.
For ABS, use acetone vapor smoothing to polish surfaces.
Note:
Don’t over-sand locking features to prevent looseness.
3. Heat Treatment (Annealing)
Purpose:
Increase strength, reduce internal stress, and improve durability.How to do it:
Place parts in an oven:
PETG: 70–80°C for 1 hour
ABS: 100°C for 30–60 minutes
Nylon: 90°C for 1–2 hours
Let them cool down slowly inside the oven to avoid warping.
Note:
Use a temperature-controlled oven—not a heat gun or open flame.
4. Fit Adjustment
Purpose:
Fine-tune the fit if it’s too tight or loose.How to do it:
Sand or trim snap arms or holes slightly.
Use a drill to widen tight holes carefully.
For deformed parts, use a low-temp heat gun to reshape.
Note:
Make gradual adjustments and test frequently.
5. Lubrication (Optional)
Purpose:
Reduce friction and wear in tight or high-cycle snap fits.How to do it:
Use dry PTFE spray or silicone-based lubricants.
Apply only to hook/slot contact areas.
Note:
Avoid petroleum-based greases—they may degrade plastic and attract dust.
6. Metal Inserts (Optional)
Purpose:
Reinforce threaded holes or structural joints for repeated use.How to do it:
Use heat-set brass inserts with a soldering iron.
Glue-in inserts are suitable for light loads.
Note:
Do not place inserts on flexible snap arms—they’ll reduce elasticity.
Common Issues & Solutions
1. Snap Arm Breaks
● Likely Causes:
Arm is too thin, short, or poorly supported.
Printed vertically (stress applied along Z-axis, causing weak layer adhesion).
Brittle material used (e.g., standard PLA).
● Solutions:
Increase arm thickness, length, or add fillets at the base.
Use more ductile materials like PETG, Nylon, or TPU.
Orient the arm horizontally (in XY-plane) for stronger layer bonding.
Increase nozzle temperature to enhance interlayer adhesion.
Post-process with acetone (ABS) or enable ironing to reduce stress points.
2. Too Tight
● Likely Causes:
Insufficient clearance between mating parts.
Thermal shrinkage (especially with ABS or PETG).
Rough surfaces from blobs or print defects.
● Solutions:
Add 0.3–0.5 mm clearance between mating surfaces.
Apply chamfers or tapers to entry points.
Sand or polish surfaces for smoother fitting.
Use dimensionally stable materials for tighter tolerance fits.
3. Snap Becomes Loose Over Time
● Likely Causes:
Material fatigue from repeated snapping.
Creep or deformation under sustained load or high temps.
● Solutions:
Switch to fatigue-resistant materials (e.g., Nylon, ASA, TPU).
Reinforce design with thicker hinges, dual arms, or stop features.
Avoid prolonged exposure to heat or static loads.
4. Print Warping or Weak Snaps
● Likely Causes:
Poor bed adhesion, especially with large or thin parts.
Low infill density or inadequate wall count.
Excessive cooling (e.g., PLA prints warping or cracking).
● Solutions:
Use brims, rafts, or enclosures for better bed adhesion.
Increase wall count (≥3) and infill density (≥60%).
Reduce cooling fan speed for PETG/ABS to avoid layer separation.
5. Hooks Won’t Latch Properly
● Likely Causes:
Deformed overhangs from poor support.
Overextrusion, elephant’s foot, or inaccurate Z-offset.
● Solutions:
Add proper support structures for angles >45°.
Calibrate Z-offset and extrusion multiplier.
Use draft angles (5–10°) on hooks for smoother latching.
6. Rough or Uneven Surface Finish
● Likely Causes:
Stringing, blobbing, or inconsistent extrusion.
Wet filament or nozzle clogging.
● Solutions:
Dry filament (especially Nylon, PETG).
Tune retraction, lower print temperature (5–15°C as needed).
Use smaller nozzles (e.g., 0.25 mm) and reduce print speed.
Typical Application Scenarios
Electronics enclosures
Snap-fit designs enable tool-free assembly and disassembly, making maintenance, repairs, or upgrades faster and more convenient. Common in cases for Raspberry Pi, Arduino shields, or consumer gadgets. Snap fits help reduce screw counts and assembly time.
Consumer products
Widely used in toys, battery compartments, remote controls, wearable devices, and household appliances. Snap fits allow easy battery replacement or modular part swapping while maintaining a secure hold during use.
Modular mechanical parts
Snap-fit connectors facilitate modularity and customization in mechanical assemblies such as jigs, fixtures, robotic parts, or interchangeable tool attachments. They enable quick configuration changes without hardware tools.
Prototype testing and iterative design
Rapid prototyping benefits from snap-fit joints by allowing quick assembly/disassembly of parts for testing fit, function, and ergonomics. This is especially useful in early design validation and functional mockups before final tooling.
Automotive and industrial applications
Durable snap fits can replace screws or rivets in non-structural components like interior panels, clips, and fasteners, reducing weight and simplifying assembly lines. Materials like Nylon or ASA are preferred for durability and environmental resistance.
Medical devices and wearables
Snap fits are used for parts requiring frequent opening and closing, such as sensor housings or adjustable straps, where hygiene and user convenience are priorities.
FAQs
1. What are the three types of snap-fit joints?
The three main types of snap-fit joints are:
Cantilever Snap-Fits
: The most common type, using a flexible arm that bends to engage a catch.
Annular Snap-Fits
: Circular or ring-shaped features often used in caps, lids, and enclosures.
Torsional Snap-Fits
: Use twisting or rotating motion to engage and disengage the joint.
2. What is the snap-fit technique?
Snap-fit is a tool-free assembly technique where two parts are joined using elastic deformation. One part has a protruding feature (like a hook or bead) that snaps into a corresponding recess on the other part, creating a secure, reusable connection.
3. What is the alternative to snap-fit?
Alternatives to snap-fit joints include:
Screws or bolts
– for permanent or strong assemblies.
Adhesives
– for seamless, fixed bonding.
Heat staking or ultrasonic welding
– for plastic-to-plastic fusion.
Magnetic or friction fits
– for modular or temporary connections.
Follow me on Linkedin
Allen Yang
A seasoned engineer and the CEO of Unionfab, Allen has spent over 10 years bridging the gap between rapid prototyping and full-scale production.
Visit Our Factories Online
Ready For Production?
Get An Instant Quote
Recent Articles
Materials
5
mins
Unionfab Lowers Metal Printing Prices by Up to 46%
Unionfab has updated pricing across selected 3D printing materials, including both metal and resin options.
Sep 1, 2026
Read More
Post Processing
4
mins
Black Oxide vs. Phosphate Coating: Choosing the Right Surface Treatment for Steel Components
Compare phosphate coating vs black oxide for steel parts. Learn the differences in corrosion resistance, paint adhesion, dimensional impact, appearance, and best-use applications.
Sep 1, 2026
Read More
Design Guides
19
mins
Metal AM Material DFM Guide
This guide is about how to select alloys, design for laser powder bed fusion, and control cost, qualification risk, and production readiness.
Sep 1, 2026
Read More
Unionfab is China's Largest 3D Printing Manufacturing Company for Rapid Prototyping and On-Demand Production Parts.
Privacy Policy
｜
Terms of Service
Quick Links
3D Printing
CNC Machining
Vacuum Casting
Materials
Contact Us
Resources
Knowledge Base
Help Center
Case Studies
Videos
Copyright Notice 2026 © Unionfab.com All Rights Reserved.
沪ICP备17023219号-3
Region:
-
, Version:
26.09.2401

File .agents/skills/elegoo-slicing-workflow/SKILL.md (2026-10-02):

---
name: elegoo-slicing-workflow
description: >-
  Guidance, best practices, and troubleshooting for slicing 3D models with Elegoo Slicer
  (OrcaSlicer fork) on the Elegoo Centauri Carbon 2 (ECC2). Use whenever preparing prints,
  resolving slicer warnings (floating cantilever, floating regions), configuring PETG bed
  temperatures, choosing between Normal vs Tree supports, or diagnosing multi-plate 3MF files.
---

# Elegoo Slicer (Centauri Carbon 2) Slicing & Troubleshooting Guide

This guide documents verified configurations, common pitfalls, and resolution workflows for slicing functional FDM prints using **Elegoo Slicer** (OrcaSlicer 2.4+ fork) targeting the **Elegoo Centauri Carbon 2 (ECC2)**.

---

## 1. Machine & Environment Setup

* **Target Printer**: Elegoo Centauri Carbon 2 (Build Volume: $256 \times 256 \times 256\text{ mm}$).
* **Slicer Executable**: `/opt/elegoo-slicer/AppRun` (or `/usr/bin/elegoo-slicer`).
* **Active System Profiles**:
  * Machine: `~/.config/ElegooSlicer/system/Elegoo/machine/ECC2/Elegoo Centauri Carbon 2 0.4 nozzle.json`
  * Filament: `~/.config/ElegooSlicer/system/Elegoo/filament/ECC2/Elegoo Rapid PETG @ECC2.json`
  * Process: `~/.config/ElegooSlicer/system/Elegoo/process/ECC2/0.20mm Standard @Elegoo CC2 0.4 nozzle.json`

---

## 2. Common Errors & Exact Solutions

### A. Red Banner: "Cool Plate is not suggested for use printing filament 1 (Elegoo Rapid PETG)..."

* **Symptom**: Slicer prevents slicing or shows a red error banner complaining bed temperature is $0^\circ\text{C}$.
* **Root Cause**: Elegoo Slicer / OrcaSlicer defaults `curr_bed_type` to `"Cool Plate"`. The Rapid PETG profile defines Cool Plate temperature as $0^\circ\text{C}$ (unsupported).
* **Fix**:
  1. In GUI: In the top-left plate dropdown, change **Bed Type** from **Cool Plate** to **Textured PEI Plate**.
  2. In 3MF `Metadata/project_settings.config`:
     ```json
     "curr_bed_type": "Textured PEI Plate",
     "default_bed_type": "4"
     ```
  3. This automatically engages the correct **$70^\circ\text{C}$** bed temperature for Rapid PETG.

---

### B. "Do I click Auto Orient All?" -> NEVER (DON'T)

* **Rule**: **NEVER click "Auto Orient" on pre-oriented CAD / bed STLs.**
* **Why**: Pre-oriented parts have been intentionally rotated so that:
  * Layer lines align with mechanical shear/bending stresses (critical for snap-fit arms).
  * 45° overhangs (like diamond ventilation mesh) are self-supporting.
  * Clicking Auto Orient rotates the model arbitrarily, ruining self-supporting geometry and requiring massive supports.

---

### C. Warning: "...has floating cantilever. Please re-orient the object or enable support generation."

* **Symptom**: The slicer warns of a floating cantilever (e.g. on horizontal snap arms at high Z elevations).
* **Rule**: **DO NOT IGNORE.** If ignored, the printer will extrude molten filament into mid-air, causing spaghetti and structural failure.
* **Support Choice: Normal vs Tree**:
  * **When to use Normal Support (`normal(auto)`) [RECOMMENDED for snap arms]**:
    * If the overhang has a direct vertical line down to the build plate.
    * **Filament Savings**: Consumes drastically less filament (~8.8g vs 50g+ for thick tree trunks).
    * **Print Speed**: Slices and prints significantly faster.
    * **Rigidity**: Forms sturdy, vibration-resistant rectangular vertical columns.
  * **When to use Tree Support (`tree(auto)`)**:
    * Only when the support must reach around or snake past another section of the model to reach the overhang.
* **Essential Support Settings**:
  * **`[x] On build plate only`**: Always enable to prevent support structures from growing on top of finished model surfaces.
  * **`Top Z distance: 0.20 mm` (or `0.25 mm`)**: Critical for PETG. Because PETG adheres strongly, a 0.20–0.25 mm gap ensures clean, tool-free snap-off without tearing the part.

---

### D. Warning: "...has floating regions. Please re-orient the object or enable support generation."

* **Symptom**: Slicer detects that a nominally flat plate has floating islands when flipped face-down on the bed.
* **Root Cause**: Features intended for grip (finger pads, pull ribs) were raised $+0.6$ to $+1.4\text{ mm}$ above the roof plane. Flipping the part face-down rests the entire weight on the tiny raised features, suspending the main plate in mid-air.
* **Design Fix**:
  * In CAD, **deboss / recess** the grip grooves ($-0.6\text{ mm}$ into the surface) like a battery door.
  * The outer face remains 100% planar on the PEI bed ($Z=0$), printing **100% support-free with 0 warnings**.

---

### E. Multi-Plate Tree Support Collision (`Potentially lost branch!`)

* **Symptom**: Slicing multiple tall objects on the same plate with tree support crashes CLI slicer with exit code 155 (`Error: Potentially lost branch!, critical: 1`).
* **Root Cause**: Automatic tree generation calculates branch trajectories that collide between adjacent parts.
* **Solution**:
  * Put parts on **dedicated plates** (`Plate 1`, `Plate 2`, `Plate 3`), or
  * Use separate `.3mf` files per part (e.g. `01_front_case.3mf`, `02_back_case.3mf`, `03_service_lid.3mf`).

---

## 3. Recommended Process Profile for Functional PETG Parts

| Setting | Recommended Value | Reason |
| :--- | :--- | :--- |
| **Layer Height** | `0.20 mm` Standard | Optimal balance of layer adhesion and detail |
| **Wall Loops** | `4` (1.6 mm solid perimeter) | Optimal for load-bearing and snap-fit flexural fatigue life |
| **Sparse Infill** | `15% Gyroid` | Isotropic load bearing; no crossing grid collisions |
| **Top / Bottom Shells**| `4` solid layers | Prevents pillowing and ensures watertight roofs |
| **Nozzle Temp** | `250°C` (Rapid PETG) | Maximum inter-layer bond strength |
| **Bed Temp** | `70°C` (Textured PEI) | Reliable first layer adhesion without warping |
| **Cooling Fan** | `20% - 40%` | Moderate cooling prevents PETG brittleness & layer delamination |
| **X-Y Hole Comp** | `+0.10 mm` | Compensates internal diameter shrinkage for switches & screws |
| **Elephant Foot** | `0.15 mm` | Prevents first-layer squish ridge from jamming slide fits |

---

## 4. Headless CLI Slicing Commands

Run headless slicing and capture machine results:

```bash
# 1. Slice a 3MF file to check validity and warnings
/opt/elegoo-slicer/AppRun \
  --slice 0 \
  --outputdir /tmp \
  /path/to/project.3mf && cat /tmp/result.json

# 2. Slice with explicit custom process JSON
/opt/elegoo-slicer/AppRun \
  --load-settings "/path/to/custom_process.json;/home/indra/.config/ElegooSlicer/system/Elegoo/machine/ECC2/Elegoo Centauri Carbon 2 0.4 nozzle.json" \
  --load-filaments "/home/indra/.config/ElegooSlicer/system/Elegoo/filament/ECC2/Elegoo Rapid PETG @ECC2.json" \
  --slice 0 \
  --outputdir /tmp \
  /path/to/model.stl && cat /tmp/result.json
```

A clean, successful slice returns:
```json
{
  "error_string": "Success.",
  "return_code": 0,
  "sliced_plates": [
    {
      "id": 1,
      "warning_message": ""
    }
  ]
}
```

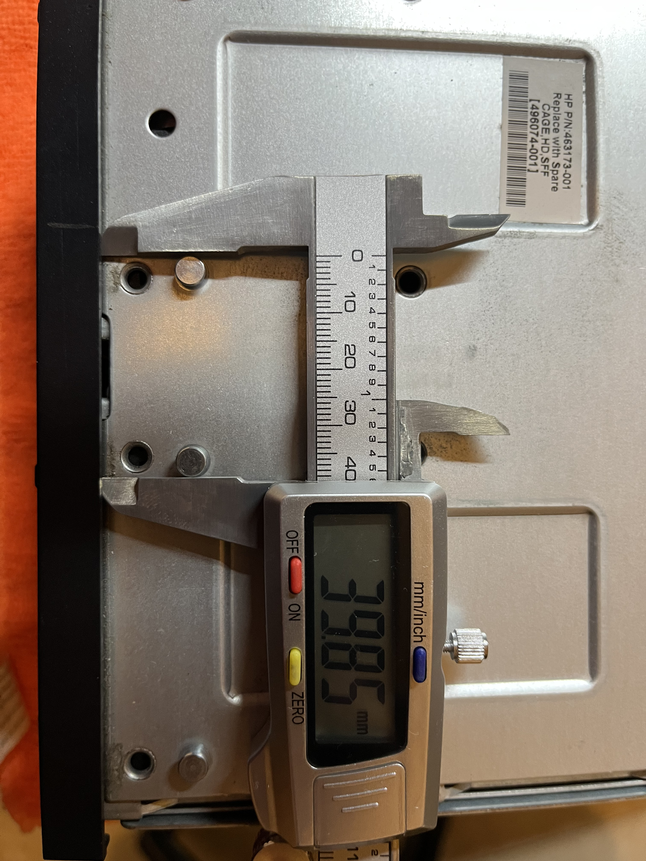
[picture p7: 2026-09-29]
docs/digital_capler/top-moshrom-center.jpeg

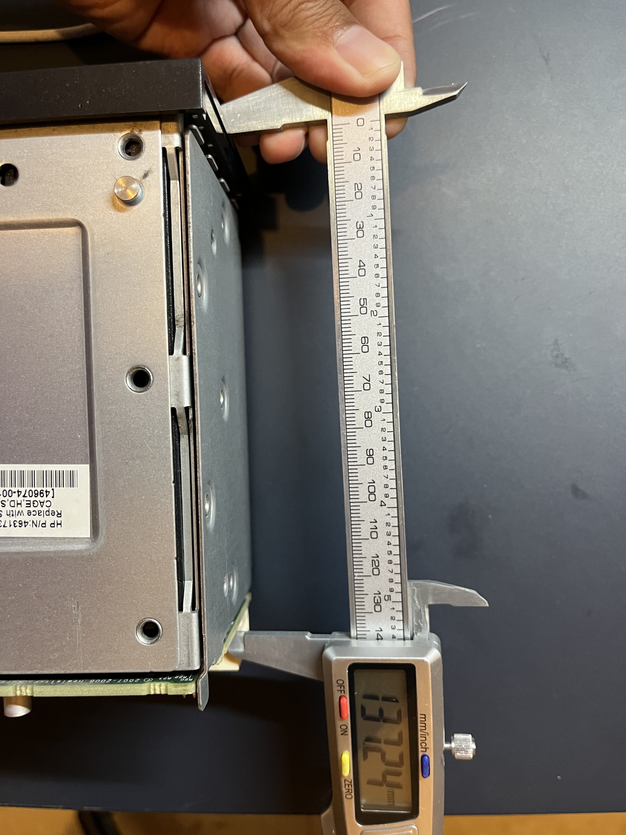
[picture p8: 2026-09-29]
docs/digital_capler/plastic-front-to-backplane-long.jpeg

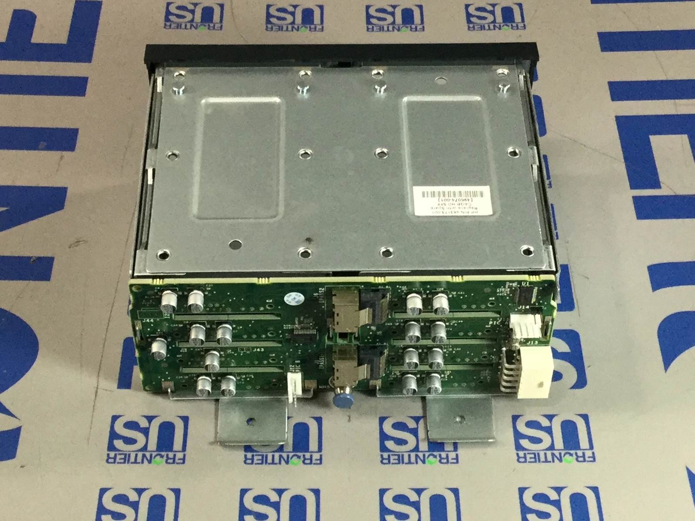
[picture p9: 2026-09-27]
docs/reference/s-l1600.webp

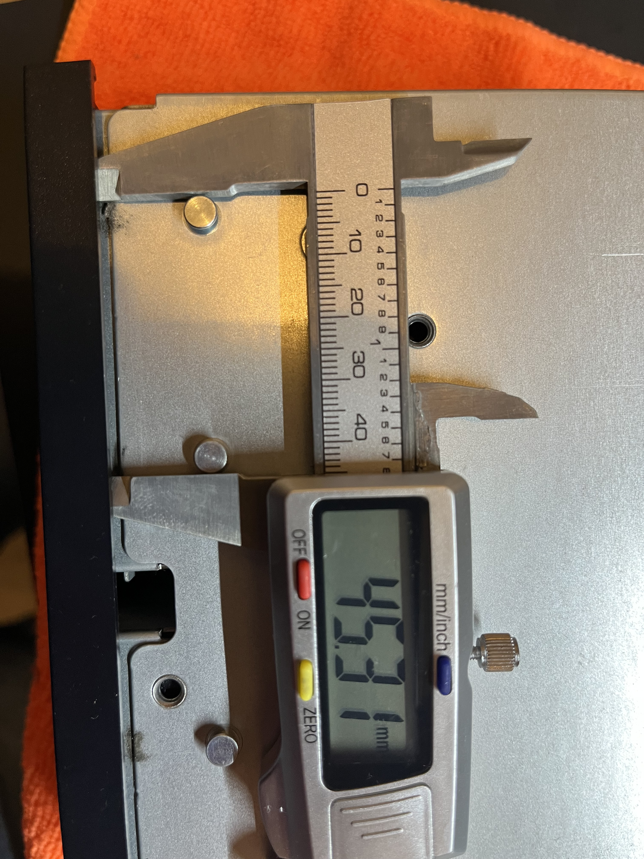
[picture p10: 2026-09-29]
docs/digital_capler/bottom-mosrom-right.jpeg

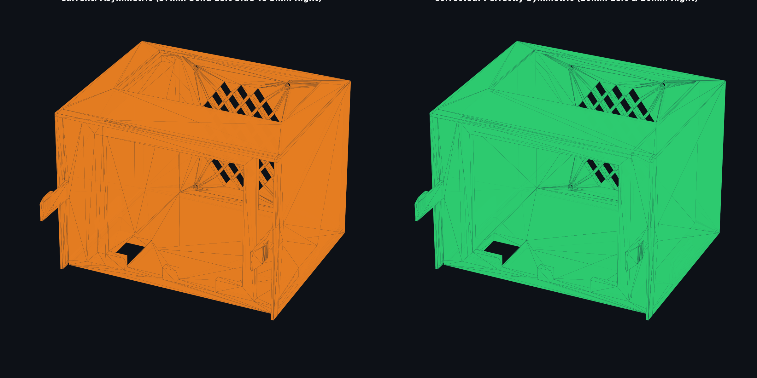
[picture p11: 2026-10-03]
docs/02B_wall_symmetry_comparison.png

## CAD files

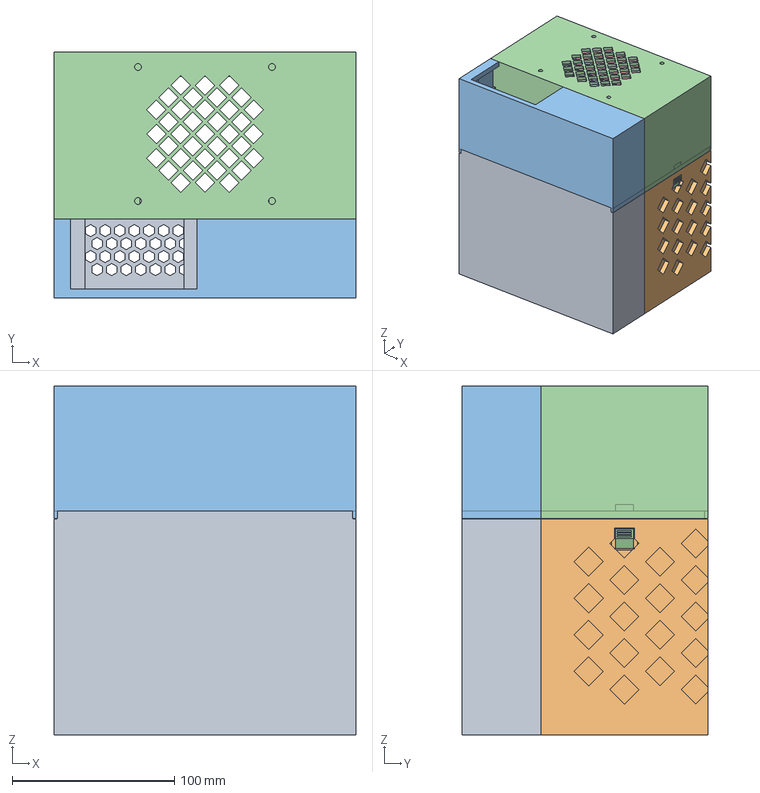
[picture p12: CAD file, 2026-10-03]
out/4piece/dl380_4piece_assembly.step
186.0 x 151.5 x 215.0 mm

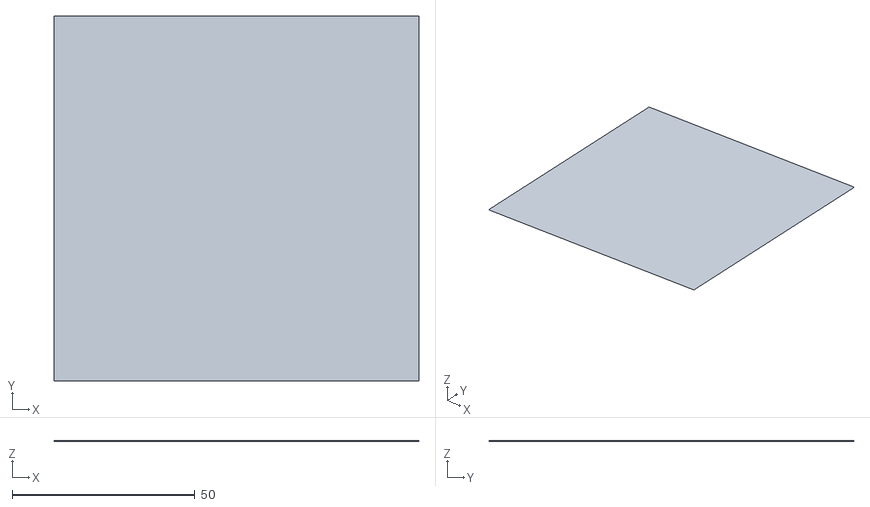
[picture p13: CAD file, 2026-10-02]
calibration/bed_level_test_single_100x100.stl
100.0 x 100.0 x 0.2

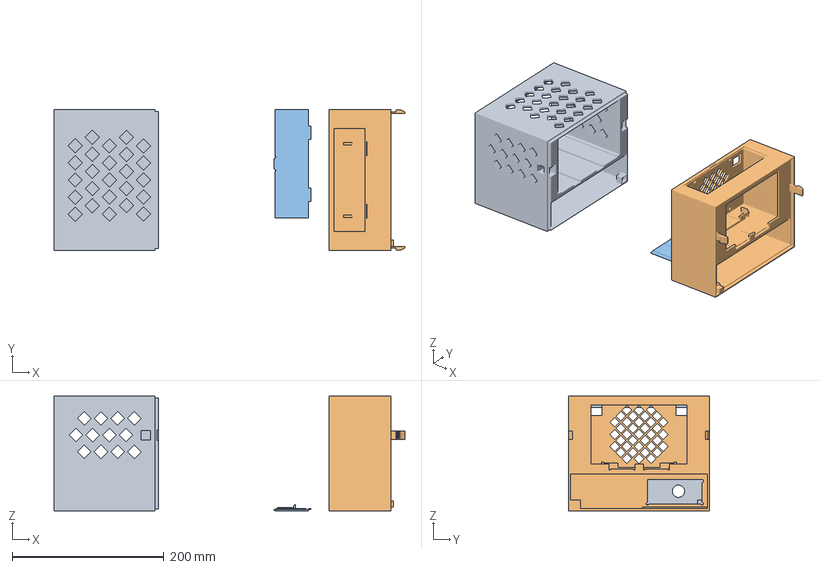
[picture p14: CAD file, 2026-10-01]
DL380_Centauri_Carbon_Project.3mf
462.7 x 186.0 x 151.5 mm
01_front_case_bed.stl
02_back_case_bed.stl
03_service_lid_bed.stl

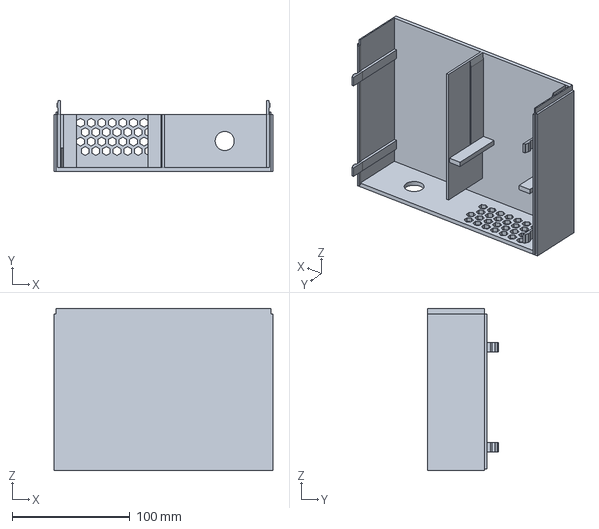
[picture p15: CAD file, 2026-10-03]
out/4piece/01A_lower_front.step
186.0 x 60.5 x 138.0 mm

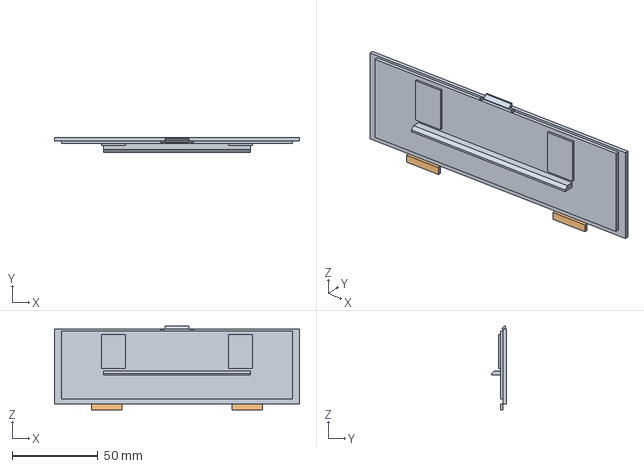
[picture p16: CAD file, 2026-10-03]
out/dl380_service_lid.step
143.0 x 8.50 x 49.0 mm

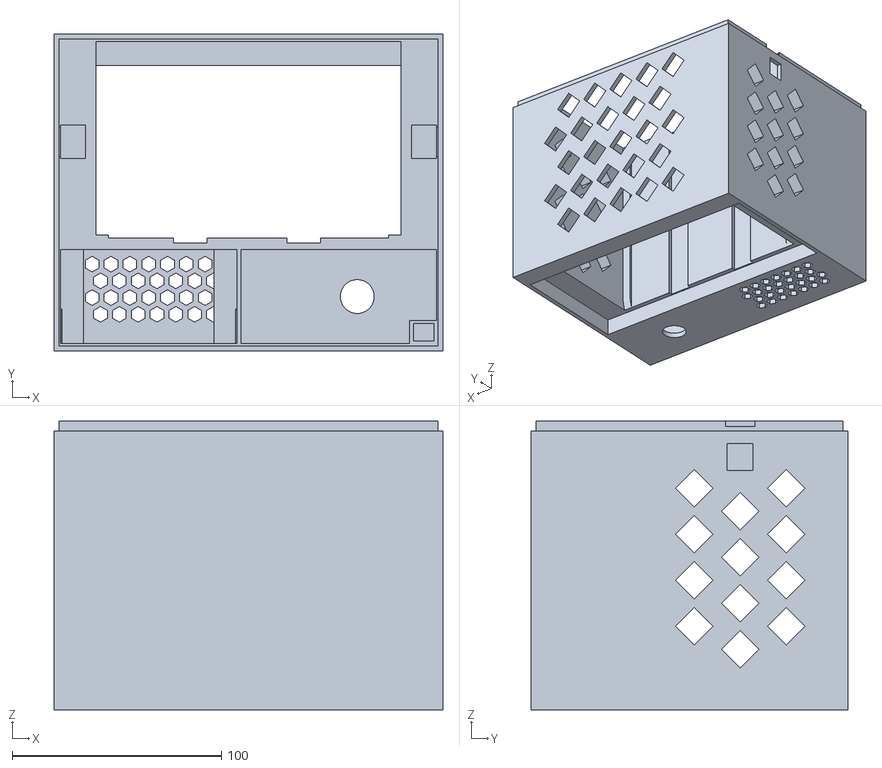
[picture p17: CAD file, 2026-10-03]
print/dl380_front_case_clean.stl
186.0 x 151.5 x 138.0

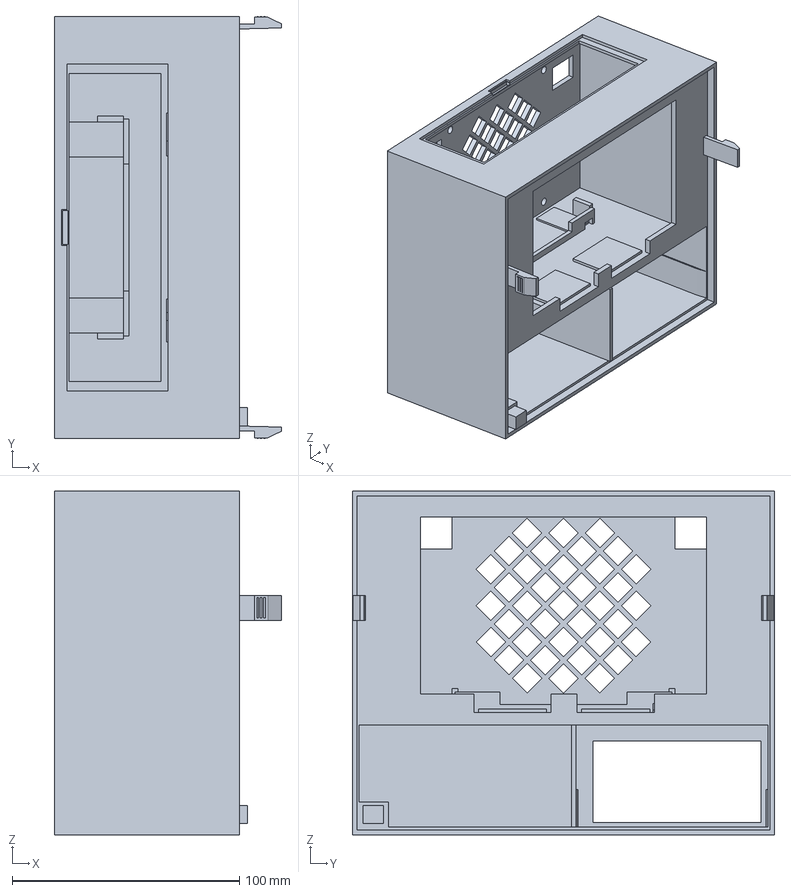
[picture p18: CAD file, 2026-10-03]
print_service_package/clean_no_supports/02_dl380_back_case_clean_no_sup.3mf
100.0 x 186.0 x 151.5 mm

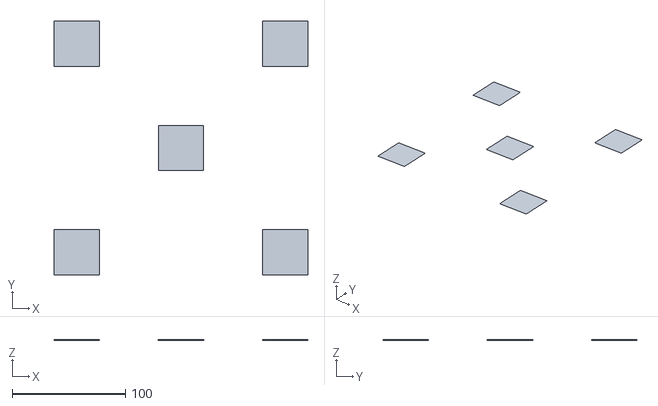
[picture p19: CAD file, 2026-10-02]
calibration/bed_level_test_5_squares_256x256.stl
224.0 x 224.0 x 0.2

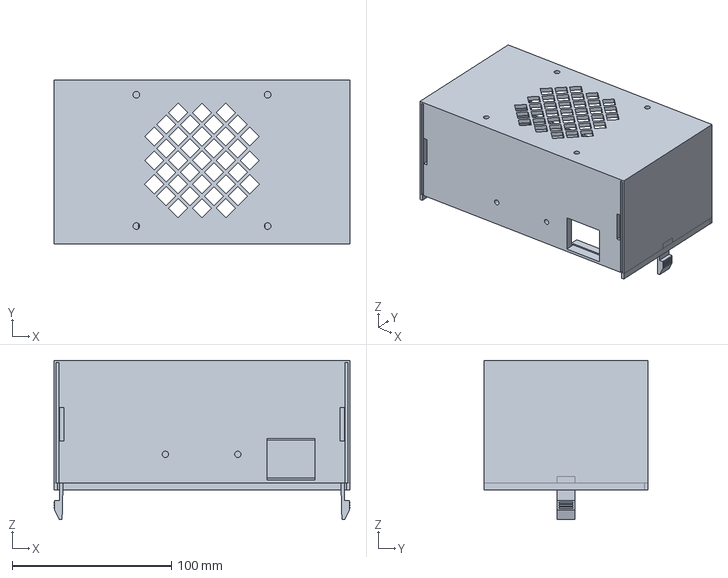
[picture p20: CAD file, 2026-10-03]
out/4piece/02B_upper_back.step
186.0 x 103.0 x 100.0 mm

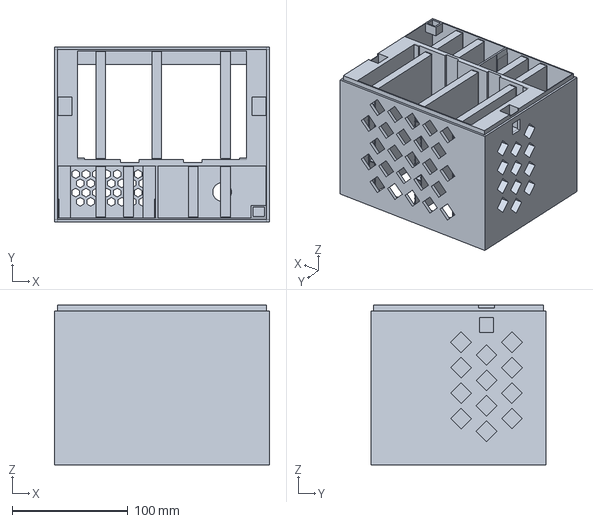
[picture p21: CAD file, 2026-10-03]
out/dl380_front_case.step
186.0 x 151.5 x 138.0 mm

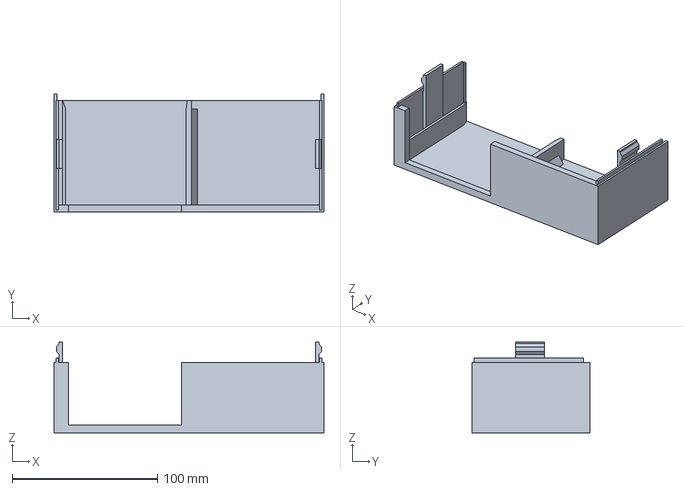
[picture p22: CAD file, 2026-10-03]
print_service_package/4piece/02A_dl380_lower_back.3mf
186.0 x 81.5 x 62.5 mm

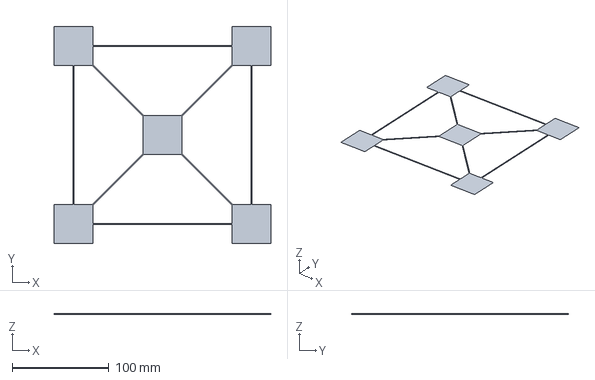
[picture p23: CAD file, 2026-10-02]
calibration/bed_level_test_PETG_256x256.3mf
224.0 x 224.0 x 0.2 mm

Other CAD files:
print_service_package/4piece/01A_dl380_lower_front.3mf
print/dl380_back_case_clean.stl
print_service_package/clean_no_supports/01_dl380_front_case_clean_normal_sup.3mf
out/4piece/02A_lower_back.step
calibration/bed_level_test_PLA_256x256.3mf
calibration/bed_level_test_connected_256x256.stl
out/4piece/01A_lower_front_bed.stl
out/4piece/01B_upper_front.step
out/4piece/01B_upper_front_bed.stl
out/4piece/02A_lower_back_bed.stl
out/4piece/02B_upper_back_bed.stl
out/4piece/03_service_lid.step
out/4piece/03_service_lid_bed.stl
out/4piece/04_drive_cage_pin.step
out/4piece/04_drive_cage_pin_bed.stl
out/4piece/04_drive_cage_pins_x4_bed.stl
out/dl380_back_case.step
out/dl380_back_case.stl
out/dl380_back_case_clean.step
out/dl380_back_case_clean.stl
out/dl380_cage_case.step
out/dl380_cage_case_body.step
out/dl380_cage_case_body.stl
out/dl380_cage_case_lid.step
out/dl380_cage_case_lid.stl
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

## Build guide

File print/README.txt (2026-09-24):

DL380 drive-cage enclosure - print kit
======================================

part             volume    solid   printed  cost @ 600/g                bbox (mm) triangles
--------------------------------------------------------------------------------------------
body           572.0 cm3    727 g     545 g  Rp    326.926   208.4 x  253.4 x 102.8     31506
lid             65.8 cm3     84 g      63 g  Rp     37.615   112.8 x  211.7 x  13.0       736
psu-strap        4.3 cm3      5 g       4 g  Rp      2.439    69.2 x   14.0 x  10.0        44
--------------------------------------------------------------------------------------------
TOTAL          642.1 cm3    816 g     612 g  Rp    366.981

The combined file lays all three out in 331.2 x 253.4 x 102.8 mm - fits a 340 x 320 plate.

WHAT THIS IS
  Three printed parts for an external enclosure that turns an HP ProLiant DL380
  G6/G7 8-bay 2.5" SFF drive cage (with backplane) into a standalone, fan-cooled
  JBOD box.  Fan, PicoPSU, grille, cable exits and DC jack all live in the body.
  Slide-and-click lid and snap-fit PSU strap mean 100% screwless enclosure assembly.

UNITS
  Millimetres.  STL and OBJ carry no units, so please import as mm.

FILES
  dl380-case_body.stl / .obj        x1   the main part
  dl380-case_lid.stl  / .obj        x1   toolless slide-and-click cover
  dl380-case_psu-strap.stl / .obj   x1   small snap-fit retaining strap
  dl380-case_all-parts.stl / .obj   x1   the same three solids in one file,
                                         already laid out side by side for the
                                         plate.  Use this if you prefer a single
                                         file for the whole job.

ORIENTATION
  Every file is already rotated so the face that should sit on the build plate
  is at Z = 0, and each part's minimum X and Y are at 0.  No reorientation and
  no re-arranging is needed - they can be sliced as they arrive.

SUPPORTS
  None required.  The parts are designed to print unsupported: the internal 45
  degree gussets carry the roof, and the exhaust grille is punched through a
  3 mm membrane rather than the full wall.

SUGGESTED SETTINGS
  Material          PETG (the plenum sees warm server air)
  Layer height      0.2 mm
  Perimeters        3
  Infill            15%
  Top/bottom        4-5 layers
  Nozzle            0.4 mm - do not go larger.  The grille webs are 1.2 mm, i.e.
                    three 0.4 mm lines, and a bigger nozzle would close them up.

WEIGHT AND COST  (PETG at 1.27 g/cm3)
  Solid (100% infill, upper bound)  :   816 g   Rp 489.307
  Printed (3 perimeters, 15% infill):   612 g   Rp 366.981

  Please quote from your own slice of these files.  The solid figure is the CAD
  volume and is the absolute ceiling; the printed figure assumes 3 perimeters and
  15% infill, which is where this part actually lands because 71% of its volume
  is wall rather than infill.

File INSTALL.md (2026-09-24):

# Installation guide

How to assemble the DL380 case. Read the **Order of work** section first — several
steps are only possible in one sequence.

Run `freecadcmd dl380_cage_case.py` first if `out/` is empty; the numbers below come
from [`out/dl380_cage_case_report.txt`](out/dl380_cage_case_report.txt).

---

## Conventions

The model uses these axes, and this guide uses them throughout:

| Direction | Meaning |
|---|---|
| **front** | the big open rectangular mouth — where caddies are inserted |
| **back / rear** | the face with the honeycomb grille, cable slots and DC jack |
| **top** | the face with the long service opening and the screwed-on lid |
| **inside** | the plenum behind the backplane — reached through the top opening |

There is **no way in from the back**. Everything except the cage goes in through the
top service opening or the front mouth.

---

## What you need

**Printed**

| Part | File | Notes |
|---|---|---|
| Body | `out/dl380_cage_case_body.stl` | the big one; prints flat on its base, front opening up, **no supports** |
| Service lid | `out/dl380_cage_case_lid.stl` | prints flat |
| PSU strap | `out/dl380_cage_case_strap.stl` | prints flat |

**Hardware**

| Item | Qty | Where |
|---|---|---|
| **Mandatory screws / inserts** | **0** | **100% toolless assembly** |
| ARCTIC P9 PWM PST 92 mm | 1 | rear fan housing |
| PicoPSU-120 (31 × 44 × 21 mm) | 1 | cradle with snap-fit strap |
| Panel-mount 5.5 × 2.5 mm DC jack | 1 | rear wall counterbore |
| Rubber feet Ø12 × 2 mm | 4 | base |
| SFF-8087 → SFF-8088 cables | 2 | rear slots |
| Wago 221 lever terminals | 3 | plenum |
| *Optional: M3 heat-set inserts* | *4* | *fan mounting (only if bolting for transport)* |
| *Optional: M3 × 30 screws* | *4* | *fan mounting (only if bolting for transport)* |

**Tools**: Flush cutters and a small scraper or deburring tool. (No soldering iron or hex drivers needed for mandatory assembly!).

the assembled layout, cut open

---

## Order of work

```
 1  print + clean up
 2  dry-fit the cage                 (checks the slide between rails before wiring)
 3  fan                              <- slides straight down into rear housing slot
 4  cage, in from the FRONT          <- slides along internal bottom rails and top ribs
 5  DC jack in the rear wall
 6  SFF-8087 cables in from the back, onto the backplane
 7  wiring: PicoPSU -> Wagos -> backplane, ground PS_ON#
 8  PicoPSU into the cradle + snap-fit strap
 9  slide-and-click service lid      <- slides +Z and clicks shut
10  rubber feet
11  first power-up
```

Steps 3 and 4 can be swapped. Everything else has to be in this order: the cables
want the cradle empty, the PSU wants the cables already routed, and the lid closes
the only way in.

---

## Step 1 — print and clean up

Print the body flat on its base with the front opening pointing up. **No supports
are needed and none should be used** — the internal 45° roof gussets, 45° slide rails,
and the 3 mm grille membrane are designed to print unsupported.

The lid prints top-plate face down on the bed with skirts pointing up (45° runner grooves
are self-supporting). The strap prints flat on the bed.

Check these before you go further:

- **every outer edge is rounded** — R1.4 on the body, R1.0 on the lid, R1.4 on the
  strap.
- the 45° slide rails on the body's outer plenum walls are clean and free of z-blobs.
- the recessed catch pocket on the front vertical step ($Z = 165\text{ mm}$) is clear.
- the lid's runner grooves and cantilever latch tooth are cleanly resolved.
- the honeycomb grille is open. The webs are 1.2 mm — **three 0.4 mm lines** — so
  don't use a nozzle bigger than 0.4 mm, and don't jab them with a scraper.
- the two rear cable slots and the Ø8 DC jack hole are clear.

---

## Step 2 — dry-fit the cage

Do this now, while the box is completely empty and you can still see what you're
doing.

**The cage slides in from the front between internal guide rails — straight, not tilted, no screws.**
It enters through the 145.8 × 87.8 mm front aperture, engages the bottom slider rails and ceiling ribs, and travels 162 mm until it seats firmly against the rear stop frame.

the target cage

| | |
|---|---|
| Cage | 145.0 × 87.0 × 165.0 mm |
| Front aperture | 145.8 × 87.8 mm (framed by 29.9 mm front cheeks) |
| Internal guide rails | Bottom rails (14 mm tall) and ceiling ribs (5 mm tall) with 1.5 mm lead-in chamfers |
| Clearance | **0.4 mm per side** — a smooth slide fit |
| Lateral wiring space | **27.1 mm clear chamber** on the left for the 10-pin power socket and cable |

0.4 mm per side is a proper slide fit but it is not loose. It will jam if you
corkscrew it, so:

1. Set the case on its base on the bench.
2. Pick the cage up by both sides, backplane away from you.
3. Line the cage up square in the front mouth. The internal rails have 1.5 mm 45° chamfers to catch the cage edges.
4. Push it in **straight** — both hands, equal pressure, no rocking.
5. It should slide smoothly between the floor rails and ceiling ribs, stopping with a firm, definite feel when it meets the internal stop frame at Z = 162 mm.
6. When seated, the cage's front bezel rests flush against the front face, completely sealing the front of the enclosure.

That stop frame is a 4 mm-wide ledge with a 137.8 × 79.8 mm aperture in it. The
cage's rear butts against it and that sets the depth. The relief notch on the left
rib gives unobstructed clearance for the 10-pin backplane power header.

**If it fights you**: don't force it. Find the tight corner, lift it out, look for
print elephant-footing or blobs on the inside of the sleeve or guide rails, scrape them off, and
try again.

Pull it back out for now — you want the box empty for the fan.

---

## Step 3 — the fan (do this before the cage)

The fan is the deepest thing in the case. It has a **full-height U-channel housing with front retaining rails**:
it slides straight down into a captive vertical track and seats on the plenum floor, giving a **firm press-fit feel with zero screws**.

**Where it lands**

| | |
|---|---|
| Track | Z 219.90 → 245.00, providing an exact **25.10 mm track depth** for the 25.0 mm fan frame |
| Seat | the plenum floor — the frame's bottom edge rests on it |
| Sides (X) | two tall guide rails extending up to Y = 90.0 mm (86 mm tall) with 0.15 mm clearance per side and 2.5 mm lead-in chamfers |
| Front lips (Z-) | **front retaining rails** overlap the frame by 2.5 mm per side with top entry chamfers; clears the Ø86 mm blade opening |
| Up (Y+) | two fins on the lid later come down to 1 mm above its top edge |

**How to get it in.** The service opening in the top runs Z 165 → 245. Lower the
frame flat (hub up) into the **rear end** of that opening, over Z 220–245, and slide it down.

1. Line the frame up over the **rear end** of the opening. The guide rails and front retaining lips have generous 2.5 mm lead-in chamfers to guide the corners in smoothly.
2. Push it straight down. The fan slides snugly into the U-channel track and lands on the plenum floor.
3. It is seated when the frame's bottom edge is flat on the floor and its rear face is flush against the inside of the rear wall. The 25.10 mm track depth gives a snug press-fit feel: rock-solid with zero rattle or wobble.
4. Check the airflow arrow points **out of the back** — this fan exhausts. Also check its lead trails out of the front of the frame, not trapped behind it.
5. **Route the lead now, while there is room.** Run it forward along one side of the plenum, tucked down low against the floor, and leave it long enough to reach the Wagos.
6. That is it — no screws. When the lid is installed at step 9, its underside fins hold the top of the frame, capturing the fan in all directions.

*(Optional: If you plan on tossing the case into a backpack and want the fan permanently bolted, you can press 4× M3 inserts into the rear face from the outside and run 4× M3 × 30 screws from inside).*

---

## Step 4 — the cage, in from the front

Same slide as step 2, but now you know it fits. Push it in square and straight until
it stops on the rear frame at Z = 162 mm. The cage is captured securely between the
bottom rails and top ribs with zero screws needed.

---

## Step 5 — the DC jack

The rear wall takes a panel-mount 5.5 × 2.5 mm barrel jack at **(+70, 52)**:

| | |
|---|---|
| Jack body hole | Ø8.0 through |
| Counterbore | Ø16.0 × 5 mm deep, in the **outside** face |
| Panel the jack sees | **3.4 mm** |

The counterbore is there on purpose: the wall is 8.4 mm thick and most panel-mount
jacks won't clamp a panel that thick. Feed the jack through from **outside**, body
first, and the nut lands on the 3.4 mm floor of the counterbore. Solder your leads
to the tags on the inside before you tighten it down.

---

## Step 6 — the SFF-8087 cables

There are two slots in the rear wall, both at **X = −70**, at **Y = 33** and
**Y = 50**, each 17 × 12 mm with rounded corners. Do these before the PicoPSU goes
in — you need the cradle empty to get your hand in.

1. From **outside**, feed each SFF-8088 overmould through its own slot, in to the
   plenum. One cable per slot.
2. Reach in through the top opening and pull the tail forward to the backplane.
3. Plug both SFF-8087 ends into the backplane, reaching forward past the front edge
   of the opening to Z 165.
4. Pull the slack back so the cables lie along the **left-hand side** of the plenum
   and leave the middle clear for the PSU.

---

## Step 7 — wiring & Wago layout

The HP DL380 G6/G7 backplane features a 10-pin power socket that faces to the **bottom-right (+X)** when the cage is upright.

**Plenum clearance**:
- The plenum and bay are **200 mm wide internally (205.6 mm outside)**, providing **27.1 mm of
  clearance** to the right of the cage and backplane PCB ($X = +72.9\text{ mm}$ to $+100.0\text{ mm}$).
- An internal stop rib notch on the lower right at $X = +68.9 \to +72.9\text{ mm}$ ($Y = 4 \to 50\text{ mm}$)
  ensures the connector housing seats cleanly without obstruction, while leaving the entire left stop rib solid.
- The 10-pin cable plugs in from the right and bends backward into the plenum.

**Wago lever block placement**:
- The transverse PicoPSU cradle is shifted to the left ($X = -40.0\text{ mm}$),
  leaving **117.2 mm of wide, open floor on the right (X = -17.2 to +100.0 mm)**.
- Place three Wago 221 lever connectors (12 V, 5 V, Ground) on the open floor on the
  right side.
- Connect the 10-pin backplane power leads and PicoPSU outputs into the Wago blocks:
  - Yellow: 12 V (from PicoPSU 12 V rail & external DC input)
  - Red: 5 V (from PicoPSU 5 V rail)
  - Black: Ground (common ground for backplane, PicoPSU, and DC jack)

**Crucial PicoPSU configuration**:
- **There is no motherboard in this box**, so a PicoPSU will not start on its own.
  Its **PS_ON# pin (green wire on 24-pin ATX) must be tied to ground** (black wire)
  for it to turn on as a standalone power supply.
- Connect the ARCTIC P9 fan (12 V and Ground) to the corresponding Wago blocks.

---

## Step 8 — the PicoPSU into the cradle + snap-fit strap

The cradle is sized for the **bare picoPSU-120 board, 31 × 44 × 21 mm**, oriented
**transversely (44 mm across X, 31 mm along Z)** at $X = +40.0\text{ mm}$.

| | |
|---|---|
| Cradle bore | 45.6 (across X) × 32.6 (along Z) mm (0.8 mm clearance per side) |
| Cradle Z | 177.0 → 209.6 mm |
| Board sits on | a 3 mm plinth, so the solder side never touches the floor |
| Front lip | 6 mm tall — 3 mm above the plinth |
| Backplane gap | the mouth is 12 mm behind the backplane; the board stops 13.6 mm short of it |
| Snap strap | 67.2 × 4 × 14 mm snap-fit clip with 0.8 mm undercut catch teeth |

1. Route the output harness and the DC input leads out of the cradle toward the
   left/front before dropping the board in.
2. Lower the board into the cradle at $X = +40.0\text{ mm}$.
3. The 6 mm front lip prevents the board from sliding forward.
4. Take the **snap-fit strap** and press it down over the cradle corner bosses.
   The compliant legs flex outward over the retention ledges and click
   firmly into place. **No screws, no tools.**

---

## Step 9 — the slide-and-click lid

The service lid uses a **slide-and-click mechanism**: it slides forward horizontally
into 45° beveled rails on the outer plenum walls and clicks shut with an integrated
cantilever latch. **100% screwless.**

1. Check nothing is proud of the top: no cable or Wago sticking up into the opening.
2. Position the lid over the rear of the plenum, aligning the skirt runner grooves
   with the 45° slide rails on the case's outer walls.
3. Push the lid **forward (+Z)** along the rails. It slides smoothly toward the front.
4. As it reaches the front step ($Z = 165\text{ mm}$), the cantilever snap latch
   tooth will ride up over the step bevel and **click audibly** into the recessed
   catch pocket.
5. The lid is now locked in all 6 degrees of freedom:
   - X and Y restrained by the 45° interlocking rails.
   - -Z restrained by the front vertical step.
   - +Z restrained by the snap latch tooth.

**To remove the lid:** Hook your index finger into the **front pull ring** (Ø14 mm hole at front center) and pull backward. The snap latch disengages and the lid glides open smoothly along the slide rails.

**Fan retention:** The fan is captured firmly on all four vertical corners by the body's full-height press-fit U-channel track and front retaining rails. The lid underside is flush, providing a smooth, clean ceiling over the plenum without internal fins.

---

## Step 10 — rubber feet

Four Ø12 × 2 mm recesses in the base at (±61, Z 14) and (±61, Z 239.4). Push-fit; a
dab of cyanoacrylate if they're loose.

---

## Step 11 — first power-up

1. Before applying power: **no loose wires trapped between lid and body**, no bare
   conductor touching the backplane or sheet metal cage.
2. Power up and confirm the fan spins and pushes air **out of the back**. Hold a
   tissue near the grille — it should be pushed away, not sucked in.
3. If the fan doesn't run, check the PS_ON# jumper first (step 7).
4. Run it for ten minutes and feel the rear wall and the grille. If the plenum is
   uncomfortably hot, the fan is restricted or running too slow — the P9 is PWM and
   idles quietly, so give it some duty cycle.

---

## Troubleshooting

| Symptom | Cause |
|---|---|
| Cage won't start into the mouth | the lead-in is only 0.8 mm and printing blobs or elephant-footing make it worse; scrape the sleeve and start it squarer. Don't force it — 0.4 mm/side is not a clearance you can bully |
| Something on the outside feels sharp | a print defect, not the design — every outer edge is R1.4 / R1.0. Deburr it |
| Cage stops short of the front face | something in the bay behind it, or it's wedged; lift out and look |
| Fan won't drop into the plenum | you're forward of the housing — lower it directly over Z 220–245 |
| Fan fits but rattles | the housing fit is 0.2 mm per side; lower `FAN_GUIDE_CLEAR` and rebuild |
| Fan won't go into the housing | raise `FAN_GUIDE_CLEAR`, or scrape the two rails |
| Fan lifts when I turn the case over | the lid is what holds it down — its two fins sit 1 mm above the frame. With the lid off, the fan is only held by gravity. Reduce `FAN_LID_GAP` if you want it clamped tighter |
| PicoPSU won't start | PS_ON# isn't grounded (step 7) |
| Strap won't sit down | the 24-pin ATX connector is standing up under it — move the strap along the cradle |
| DC jack won't clamp | your jack's neck is shorter than 3.4 mm; reduce `DC_JACK_DEPTH` and rebuild |
| Lid won't slide smoothly | rail tolerance or print artifacts; gently deburr the 45° runner grooves or rails |
| Lid won't click shut | check that the catch pocket at Z=165 is clear of debris or wires |

---

## If you change anything, re-check these

Two numbers in this guide are *derived* and both are printed in the build report, so
you don't have to work them out again:

- **`fan drop-in window : Z …`** — the band the fan must be lowered into. If
  `PLENUM_D`, `PSU_*` or `FAN_INSET` change and this band goes empty, the report
  prints `*** FAN CANNOT BE FITTED ***` instead of a number.
- **`opening size`** and the roof margins — the lid needs the side strips, the front
  band and the rear wall top to sit on.

Run `freecadcmd verify_step.py` after any rebuild; it probes the exported STEP and
exits non-zero if any opening is blocked or any wall is missing.

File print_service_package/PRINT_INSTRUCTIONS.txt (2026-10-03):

PETUNJUK CETAK 3D / 3D PRINTING INSTRUCTIONS
Proyek: DL380 Modular 2-Piece Desktop Enclosure with Diamond Mesh
Target Printer: Elegoo Centauri Carbon (Bed 256 x 256 x 256 mm)
Dimensi Rakitan Total: 186.0 mm (W) x 215.0 mm (D) x 151.5 mm (H)

FILE YANG DICETAK (PRINT FILES):
  1. 01_dl380_front_case.stl (Bodi Depan / Front Disc Cage Case) - 1 pcs
     - Dimensi: 186.0 x 138.0 x 151.5 mm
     - Fitur: Diamond mesh atap & samping, runner rails, slot switch 16mm, vents PSU
     - Estimasi berat: ~260 - 280 gram (PETG @ 15% infill)
  2. 02_dl380_back_case.stl  (Bodi Belakang / Rear Cooling & Power Backcase) - 1 pcs
     - Dimensi: 186.0 x 100.0 x 151.5 mm (termasuk lengan pengait snap-fit 23 mm)
     - Fitur: Dual cantilever snap-fit arms dengan push-release thumb pads, kisi exhaust fan 92mm pola 45° Diamond Mesh (100% self-supporting, bebas sagging & stringing), dudukan fan 92mm, dudukan PSU Flex-ATX C14, port SAS, slot power 10-pin
     - Estimasi berat: ~180 - 200 gram (PETG @ 15% infill)
  3. 03_dl380_service_lid.stl (Tutup Servis Atas / Snap-Fit Service Lid) - 1 pcs
     - Dimensi: 143.0 x 49.0 x 10.4 mm (termasuk front locating tabs & rear push-to-pull latch)
     - Fitur: Mekanisme snap gaya tutup baterai mainan (2x front slide tabs, cantilever hook, push-to-release tab dengan grip ribs), penjepit fan 92mm otomatis
     - Estimasi berat: ~18 gram

   Total Estimasi Berat Keseluruhan: ~460 - 490 gram (Sangat hemat, jauh di bawah 1 kg spool!)

FILE PROYEK SIAP CETAK (ELEGOO SLICER 3MF - 1-CLICK SLICING):
  Telah disediakan file proyek .3mf yang sudah terkonfigurasi otomatis dengan profil Elegoo Centauri Carbon 2, filamen Elegoo Rapid PETG, dan Textured PEI Plate (Suhu Bed 70°C, Nozzle 250°C):
  1. 01_dl380_front_case.3mf -> Bodi Depan (Support: ON -> Normal Auto / On build plate only)
  2. 02_dl380_back_case.3mf  -> Bodi Belakang (Support: ON -> Normal Auto / On build plate only)
  3. 03_dl380_service_lid.3mf -> Tutup Servis (Support: OFF / Bebas Support)

PENJELASAN ORIENTASI CETAK & PERINGATAN ELEGOO SLICER:
  1. Mengapa Orientasi Cetak TETAP Berdiri Tegak (Lantai Bawah Menempel di Bed PEI)?
     - JANGAN diubah ke posisi muka depan menempel di bed (Front Face Down)! Bezel depan memiliki ceruk recessed sedalam 11.5 mm (180 x 86 mm). Jika dibalik, seluruh muka depan akan melayang di udara dan membutuhkan ratusan gram support yang akan merusak permukaan kosmetik depan!
     - JANGAN diubah ke posisi dinding belakang di bed (Rear Face Down)! Terdapat kerah lap-joint 4.8 mm yang akan membuat layer tidak rata.
     - Posisi Berdiri Tegak di Lantai Dasar (Y=0) adalah orientasi TERBAIK: Jejak luas 186 x 138 mm menempel kuat di PEI Textured (bebas warping), kisi diamond mesh atap dan samping mencetak mandiri pada sudut 45° tanpa support, dan garis layer horizontal tampak sangat rapi dan estetik.

  2. Penopang Ruang Drive Cage (Disc Cage Enclosure) & Atap Belakang:
     - Masalah Sirip Tipis 2D (Single Blade): Bilah tipis 0.85 mm dengan leher 0.28 mm dapat bergetar dan tertekuk ke samping (lateral deflection) akibat dorongan nozzle kecepatan tinggi 300 mm/s, sehingga berisiko patah dini dan menghasilkan serabut benang kusut (mesh/spaghetti).
     - Solusi 3D Corrugated 'Green Cubic' Support Columns:
       * Seluruh sirip tipis telah diganti menjadi kolom kotak bergelombang 3D (Corrugated Cubic Box Columns selebar 8.5 mm) yang terinspirasi langsung dari struktur support Normal(auto) hijau di Elegoo Slicer / OrcaSlicer.
       * Memiliki 2 dinding sejajar (perimeter ganda 0.85 mm) yang dihubungkan oleh rusuk pengaku melintang (cross-ribs) setiap 18 mm, membentuk struktur tabung bervolume rigid dengan momen inersia >800x lebih kaku daripada bilah tipis!
       * 100% Bebas Goyang: Tidak akan melengkung atau patah saat nozzle melaju kencang pada akselerasi 10.000 mm/s².
       * Antarmuka Atap Bergerigi (Castellated Interface): Memiliki bantalan kontak mikro 1.5 mm dengan jeda celah udara, menahan ceiling bridging tetap rata sempurna tanpa risiko melebur/fusing dengan PETG.
       * Sangat Mudah Dilepas: Bagian alas memiliki leher takik keliling (perimeter score). Cukup jepit bagian tengah kolom kotak dengan tang lancip (pliers), lalu remas atau putar sedikit. Seluruh kolom akan langsung terlepas utuh (snap) dalam satu bagian bersih tanpa meninggalkan sisa serabut!

  3. Pengaturan Support Elegoo Slicer:
     - Untuk Bodi Depan (01_dl380_front_case.3mf) & Bodi Belakang (02_dl380_back_case.3mf):
       * Cukup gunakan: Normal(auto) - On build plate only
       * Support Top Z Distance: 0.20 mm
       * Slicer hanya membuat tiang support hijau di luar (untuk menopang kuping snap-fit dari build plate, ~5g filamen), sedangkan seluruh rongga dalam ditopang 100% kokoh oleh kolom kubik 3D terintegrasi.
       * Bebas dari peringatan 'floating cantilever', 100% aman dicetak!

PARAMETER SLICING YANG SUDAH DITERAPKAN DI 3MF:
  - Printer: Elegoo Centauri Carbon 2 0.4 nozzle
  - Filament: PETG (Elegoo Rapid PETG / Bambu Lab PETG Basic)
  - Nozzle Temp: 250°C - 255°C
  - Bed Temp: 70°C - 75°C (Textured PEI Plate)
  - Cooling Fan: 20% - 40% (Mencegah delaminasi layer pada lengan snap-fit)
  - Layer Height: 0.20 mm Standard
  - Wall Loops: 4 walls (1.6 mm solid perimeter untuk ketahanan beban & snap-fit)
  - Top / Bottom Solid Layers: 4 layers
  - Infill: 15% Gyroid
  - X-Y Hole Compensation: +0.10 mm (Mencegah lubang baut/switch undersized)
  - Elephant Foot Compensation: 0.15 mm (Mencegah bibir bawah bengkak & seret)
  - Support:
    * Front Case: OFF
    * Back Case: Normal(auto) - On build plate only (Top Z: 0.20 mm)
    * Service Lid: OFF

PERAKITAN (100% TOOL-FREE & SCREWLESS - TANPA BAUT SAMA SEKALI!):
  - Pemasangan PSU Flex-ATX (Tool-Free & Bebas Baut):
    * Masukkan PSU Flex-ATX (Enhance ENP-2320) ke rel pandu basement hingga mentok ke bibir stop dinding belakang. Rel samping presisi (jalur 82.80 mm untuk PSU 82.32 mm) dengan chamfer masuk 45° menjaga PSU tetap lurus dan anti-koclak.
    * Ketika Bodi Depan disatukan ke Bodi Belakang, sepasang pilar penahan kokoh (Front Push Pillars) di bodi depan otomatis menahan muka depan PSU (Z = 59.60 mm).
    * Saat kabel power AC C13 dicolokkan kencang dari belakang, dorongan ditahan 100% oleh pilar bodi depan sehingga PSU tidak akan mundur/bergeser ke depan!
    * Jendela belakang PSU berupa 1 lubang persegi panjang bersih (74.0 x 36.0 mm) memberikan akses bebas untuk colokan C14 dan ventilasi buang fan 40mm tanpa membutuhkan baut sama sekali!
    * Kabel ATX 24-pin dan CPU 8-pin keluar leluasa melalui jendela kabel selebar 62.5 mm di antara pilar pendorong depan.
  - Pasang drive cage ke Bodi Depan dan hubungkan kabel SAS/Power. Drive cage tertahan kokoh oleh socket bezel depan dan frame stop belakang tanpa baut!
  - Dorong Bodi Belakang ke Bodi Depan melalui kerah teleskopik 4.5 mm dan kunci sudut presisi hingga kedua pengait snap-fit samping berbunyi 'KLIK' terkunci rapat (100% Tool-Free!).
  - Masukkan fan 92mm ke dalam cradle dudukan belakang.
  - Pasang Tutup Servis (Lid): Masukkan 2 lidah depan lid ke dalam celah atap, lalu tekan bagian belakang lid ke bawah hingga berbunyi 'KLIK' terkunci rapat (seperti tutup baterai mainan / remote control). Penjepit fan atas akan otomatis mengunci fan 92mm tanpa baut!
  - Untuk membuka Tutup Servis (Lid): Dorong push-tab jempol di bagian belakang lid ke arah depan, lalu angkat lid ke atas.
  - Untuk memisahkan Bodi: Tekan kedua tombol push-button di sisi samping kiri dan kanan secara bersamaan ke dalam, lalu tarik Bodi Belakang mundur.
  - ZERO SCREWS, ZERO NUTS, ZERO TOOLS NEEDED!

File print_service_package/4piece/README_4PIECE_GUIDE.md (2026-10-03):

# DL380 4-Piece Modular Enclosure - Slicing & Assembly Guide

The **4-Piece Modular Architecture** separates the enclosure horizontally along the mid-deck shelf, eliminating nearly 100% of internal supports and dividing the print into small, manageable batches.

---

## 1. Slicing Benchmark Results (Elegoo Centauri Carbon 2)

*Sliced with Elegoo Slicer CLI (OrcaSlicer 2.4 engine) using Rapid PETG @ECC2 (0.20mm Standard, 4 walls, 15% Gyroid infill).*

| Deliverable (.3mf) | Support Configuration | Filament Usage | Estimated Print Time |
| :--- | :--- | :--- | :--- |
| `01A_dl380_lower_front.3mf` | None (100% Support-Free) | **166.1 g** | **9h 54m 47s** |
| `01B_dl380_upper_front.3mf` | None (100% Support-Free) | **364.4 g** | **1d 4h 34m 43s** |
| `02A_dl380_lower_back.3mf` | None (100% Support-Free) | **99.9 g** | **6h 10m 46s** |
| `02B_dl380_upper_back.3mf` | Normal Auto (Build Plate) | **308.9 g** | **1d 0h 14m 37s** |
| `03_dl380_service_lid.3mf` | None (100% Support-Free) | **17.0 g** | **1h 2m 10s** |
| `04_dl380_cage_pins.3mf` | None (100% Support-Free) | **1.7 g** | **10m 27s** |
| **TOTAL ASSEMBLY** | — | **958.0 g** | **~2.8 days total (spread over 6 fast plates)** |

---

## 2. Key Printing Advantages Over Monolithic 2-Piece

1. **Parts 01A, 01B, 02A, 03, and 04 are 100% Support-Free**:
   - The Lower cases print right-side up like open shallow trays ($60.5\text{ mm}$ tall with corner snap pillars).
   - The Upper Front case prints with its flat rear mating face on the PEI bed; runner rails, bezel shelf, and $45^\circ$ diamond mesh print straight up with zero supports.
   - Part 04 (Retention Pins) prints flat on its flanged heads with zero supports.
   - Only Part 02B requires minor build-plate support under the front snap latch arms (~$8\text{ g}$).
2. **Fast, Low-Risk Printing**:
   - Part 04 (Cage Pins 4-pack) prints in **~3 minutes** (~$1.7\text{ g}$).
   - Lower Back prints in only **~5.5 hours** (~$99\text{ g}$).
   - Lower Front prints in only **~9 hours** (~$164\text{ g}$).
   - No single part takes longer than ~30 hours. If a print is interrupted, you only reprint a single quadrant.
3. **Zero Tunnel Support Extraction**:
   - No digging pliers into deep enclosed chambers.

---

## 3. Tool-Free Drive Cage Retention Pins ("Filament Nails")

- Part 02B features two **Ø4.0 mm vertical retention holes** cut through the mid-deck shelf, perfectly aligned with the stamped mounting holes in the HP DL380 drive cage rear metal tabs ($X = 70.0\text{ mm}$ and $X = 115.5\text{ mm}$, $Z = 156.0\text{ mm}$).
- Part 04 provides custom 3D-printable **Ø3.85 mm / 4.0 mm retention nails** (`04_dl380_cage_pins.3mf`):
  - **Flanged Head**: Ø8.5 mm x 2.4 mm with 45° ergonomic perimeter bevel for tool-free finger insertion and easy fingernail removal.
  - **Friction Collar**: 4.00 mm -> 3.85 mm taper to ensure a snug, zero-rattle hold.
  - **Bullet Nose**: 45° conical tip for effortless blind drop-in alignment through the metal tab into the shelf.
  - **Zero Screws Needed**: Drop the two pins down through the rear metal tabs to lock the drive cage solidly against forward/backward sliding.
  - **Quick Batch Plate**: A 4-pack of pins (`04_drive_cage_pins_x4_bed.stl`) prints in **~3 minutes** with only **~1.7 g** of PETG.

---

## 4. Tool-Free Snap-Fit Assembly Sequence

```
Step 1: Click Upper Front (01B) down onto Lower Front (01A)
        ┌───────────────────────┐
        │  Upper Front (01B)    │  <── Drive cage bay & bezel
        ├═══════════════════════┤  <── 4x Corner Cantilever Snap Latches CLICK!
        │  Lower Front (01A)    │  <── PSU basement with pusher stops
        └───────────────────────┘

Step 2: Click Upper Back (02B) down onto Lower Back (02A)
        ┌─────────┐
        │ 02B Fan │  <── 92mm fan exhaust + service lid
        ├═════════┤  <── 2x Rear Corner Snap Latches CLICK!
        │ 02A PSU │  <── PSU rear opening & guide rails
        └─────────┘

Step 3: Slide Drive Cage into Front Bay and Slide Front into Rear Assembly
        ┌───────────────────────┬─────────┐
        │   DL380 Drive Cage    │ 92mm Fan│ <── 2x Side Push-Release Latch Arms CLICK!
        ├═══════════════════════╪═════════╡
        │     Flex-ATX PSU      │ AC / SAS│ <── Side-Wall Alignment Tongue-and-Groove
        └───────────────────────┴─────────┘

Step 4: Lock Drive Cage with Filament Retention Nails (Tool-Free!)
        Through the top service opening, push the 2x Part 04 pins through the
        metal rear tabs into the Ø4.0mm mid-deck holes. No screws required!
```

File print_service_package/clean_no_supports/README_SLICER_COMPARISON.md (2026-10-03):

# DL380 Flex Case - Slicer Auto-Support Comparison Guide

This directory contains the **Clean (Zero CAD Supports)** variant of the DL380 Modular Flex-ATX Case, allowing you to directly test, visualize, and benchmark the slicer's built-in support generation (Normal vs Tree) against our pre-engineered DfAM sacrificial columns.

---

## 1. Head-to-Head Slicing Benchmark Results

*Sourced directly from Elegoo Slicer CLI (OrcaSlicer 2.4 engine) targeting the Elegoo Centauri Carbon 2 with Elegoo Rapid PETG (0.20mm Standard, 4 walls, 15% Gyroid infill).*

| File (.3mf) | Variant | Slicer Support Mode | Total Filament | Estimated Time |
| :--- | :--- | :--- | :--- | :--- |
| `01_dl380_front_case.3mf` | Standard (DfAM Sup) | Normal (Auto, Build-Plate) | **601.0 g** | **1d 21h 58m 33s** |
| `02_dl380_back_case.3mf` | Standard (DfAM Sup) | Normal (Auto, Build-Plate) | **389.8 g** | **1d 5h 4m 29s** |
| `03_dl380_service_lid.3mf` | Lid | Disabled (None) | **18.9 g** | **1h 10m 38s** |
| `01_dl380_front_case_clean_normal_sup.3mf` | Clean (No CAD Sup) | Normal (Auto, Build-Plate) | **491.2 g** | **1d 9h 50m 8s** |
| `01_dl380_front_case_clean_tree_sup.3mf` | Clean (No CAD Sup) | Tree (Auto, Build-Plate) | **777.6 g** | **3d 3h 26m 4s** |
| `01_dl380_front_case_clean_no_sup.3mf` | Clean (No CAD Sup) | Disabled (None) | **490.4 g** | **1d 9h 45m 42s** |
| `02_dl380_back_case_clean_normal_sup.3mf` | Clean (No CAD Sup) | Normal (Auto, Build-Plate) | **345.4 g** | **1d 0h 8m 30s** |
| `02_dl380_back_case_clean_tree_sup.3mf` | Clean (No CAD Sup) | Tree (Auto, Build-Plate) | **538.0 g** | **2d 2h 6m 43s** |
| `02_dl380_back_case_clean_no_sup.3mf` | Clean (No CAD Sup) | Disabled (None) | **337.2 g** | **23h 6m 55s** |

---

## 2. Architectural Comparison: DfAM Built-in vs Slicer Auto-Support

| Feature / Criteria | Standard DfAM Built-in Columns | Slicer Normal Auto Support | Slicer Tree Auto Support |
| :--- | :--- | :--- | :--- |
| **Aperture & Void Access** | Designed for needle-nose pliers removal through existing front/rear windows | Fills large rectangular blocks from the bed | Snakes branches inward from outer bed |
| **Ceiling Finish** | Pre-scored 0.35mm neck + castellated teeth prevent PETG sagging & fusion | May fuse to PETG bridges if Z-gap < 0.20mm | Low contact surface, easy release |
| **Mid-Deck / Cable Hole** | Through-hole column supports both floors from a single rigid foundation | Cannot cross floors without resting on finished parts | Can branch through apertures |
| **Bed Adhesion Stability** | Rigid cubic cross-braced towers (zero deflection under 300 mm/s) | Solid box columns | Tall branches can wobble on high-speed CoreXY |

---

## 3. How to Use These Deliverables in Elegoo Slicer / OrcaSlicer

1. **Pre-configured .3MF Projects**:
   - `01_dl380_front_case_clean_normal_sup.3mf`: Clean Front Case with Slicer Normal Auto-Support configured.
   - `01_dl380_front_case_clean_tree_sup.3mf`: Clean Front Case with Slicer Tree Auto-Support configured.
   - `02_dl380_back_case_clean_normal_sup.3mf`: Clean Back Case with Slicer Normal Auto-Support configured.
   - `02_dl380_back_case_clean_tree_sup.3mf`: Clean Back Case with Slicer Tree Auto-Support configured.
   - `01_dl380_front_case_clean_no_sup.3mf` / `02_dl380_back_case_clean_no_sup.3mf`: Support turned OFF (ideal for custom painting manual support enforcers).
2. **Raw Bed STLs**:
   - `01_front_case_clean_bed.stl`
   - `02_back_case_clean_bed.stl`
   Import these STLs directly if you want to experiment with custom support painted regions, hybrid infill, or different slicer forks.

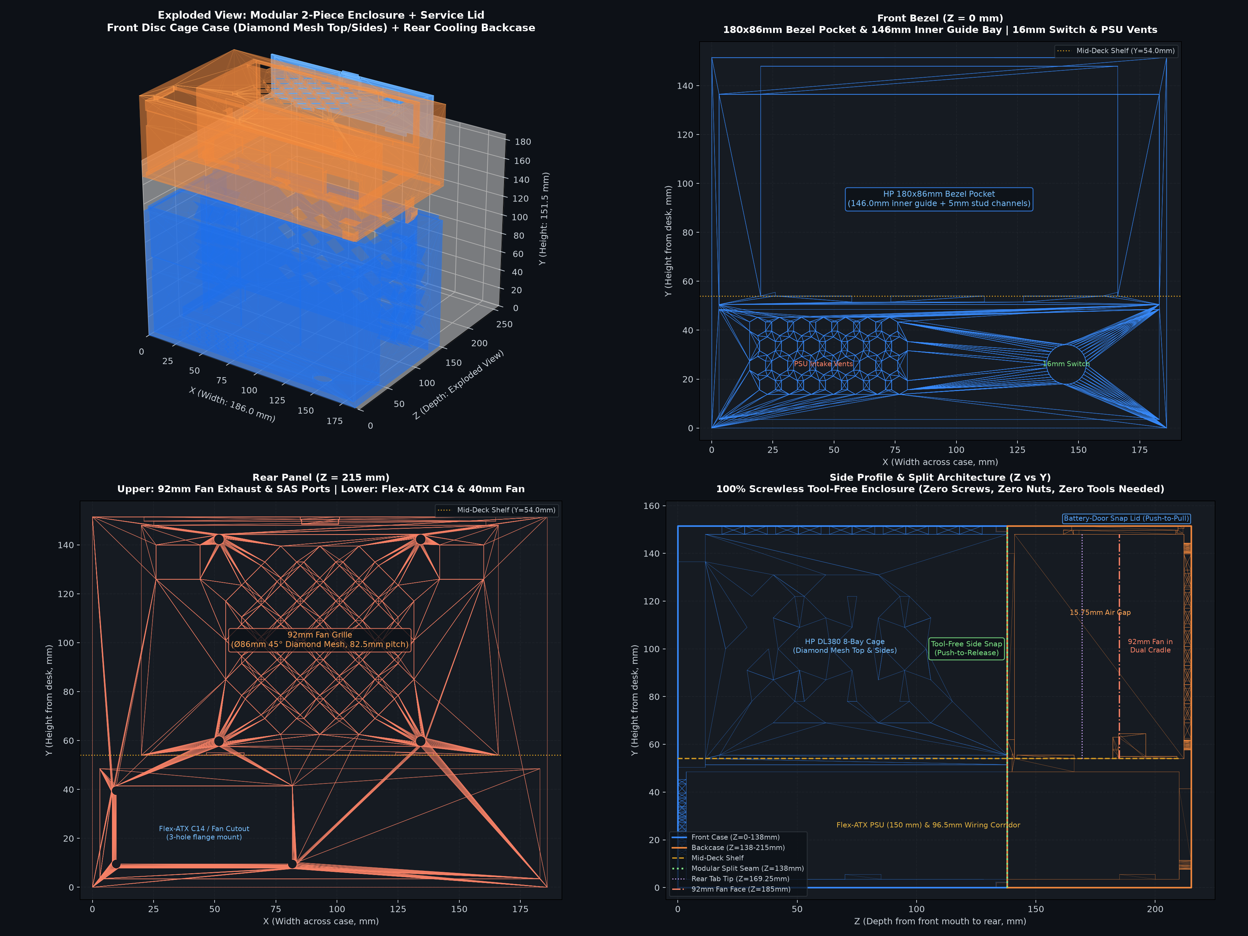
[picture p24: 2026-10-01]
print_service_package/preview_assembly_views.png

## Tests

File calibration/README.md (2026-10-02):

# First Layer Bed Level Calibration (256x256 mm)
Target Printer: **Elegoo Centauri Carbon 2 (ECC2)** (Build Volume: $256 \times 256 \times 256\text{ mm}$)

This calibration kit verifies auto-bed-leveling (ABL), bed mesh tilt, and nozzle Z-offset across the entire $256 \times 256\text{ mm}$ textured PEI build plate. It prints **exactly 1 single layer ($Z = 0.20\text{ mm}$)**, consumes under **3 grams of filament**, and completes in **~10 minutes**.

---

## 1. Included Deliverables

| File | Description | Material & Target |
| :--- | :--- | :--- |
| **`bed_level_test_PLA_256x256.3mf`** | **Ready-to-Print 1-Click Project** for CC2 Sample PLA | Nozzle: 215°C, Bed: 60°C (PEI), 1 Layer, 2.89g |
| **`bed_level_test_PETG_256x256.3mf`** | **Ready-to-Print 1-Click Project** for Bambu PETG Basic | Nozzle: 255°C, Bed: 75°C (PEI), 1 Layer, 2.89g |
| **`bed_level_test_connected_256x256.stl`** | 5 Patches ($40 \times 40\text{ mm}$) + connecting perimeter & diagonal runners | **Recommended STL**: Peels off in 1 single sheet! |
| **`bed_level_test_5_squares_256x256.stl`** | 5 detached squares at 4 corners + center ($40 \times 40 \times 0.20\text{ mm}$) | Individual patch verification |
| **`bed_level_test_single_100x100.stl`** | Single centered square ($100 \times 100 \times 0.20\text{ mm}$) | Quick center Z-offset check |

---

## 2. How to Read Your First Layer Test

Inspect the 5 squares (Center, Front-Left, Front-Right, Back-Left, Back-Right) as they print:

1. **PERFECT First Layer (Target)**:
   * Smooth, uniform top surface.
   * Extrusion lines touch each other with **zero gaps** between strands.
   * Surface feels smooth like a plastic card when rubbing your fingernail across it (no rough ridges).
2. **Nozzle Too High (Z-Offset too positive / Gap too large)**:
   * Individual extrusion strands look like loose round spaghetti threads.
   * Visible gaps or daylight between adjacent extrusion lines.
   * Squares easily separate or don't stick to the PEI bed.
   * **Fix**: Lower Z-offset on the printer touchscreen by $-0.02\text{ mm}$ to $-0.05\text{ mm}$.
3. **Nozzle Too Low (Z-Offset too negative / Nozzle dragging)**:
   * Extrusion lines have raised, rough ridges where the nozzle plows through melted plastic.
   * Patch looks transparent or very thin in some spots.
   * Extruder makes clicking/skipping noises.
   * **Fix**: Raise Z-offset on the printer touchscreen by $+0.02\text{ mm}$ to $+0.05\text{ mm}$.

---

## 3. Recommended Slicer Settings

* **Layer Height**: `0.20 mm`
* **First Layer Height**: `0.20 mm`
* **Brim**: `None (OFF)`
* **Support**: `OFF`
* **Bed Type**: `Textured PEI Plate`
* **Sample PLA Settings**: Nozzle `210°C - 215°C`, Bed `55°C - 60°C`
* **Bambu PETG Basic Settings**: Nozzle `250°C - 255°C`, Bed `70°C - 75°C`

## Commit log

2026-09-23 Add DL380 G6/G7 8-bay SFF drive cage desktop enclosure
    Parametric FreeCAD script that generates an external, 120 mm fan-cooled
    desktop enclosure for an HP ProLiant DL380 G6/G7 8-bay 2.5" SFF drive cage
    plus backplane (P/N 496074-001 and relatives).
    - 145.8 x 87.8 mm sleeve (+0.4 mm/side) with an open front for standard HP
    SFF caddies, and a 3 mm internal rear stop frame
    - 65 mm wiring plenum behind the backplane for SFF-8087 boots and Wago 221
    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
    [dl380_cage_case.step, dl380_cage_case_body.step, dl380_cage_case_body.stl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]
2026-09-23 Shrink the fan to 92 mm so the enclosure has a flat top
    The 120 mm fan from the original brief needs 105 mm of mounting pattern plus
    edge material on a rear wall whose airflow comes from an aperture only 87.8 mm
    tall. That forced a 132 mm raised rear tower and an L-shaped profile, with the
    fan axis 19 mm above the cage centreline.
    A 92 mm fan (82.5 mm pattern) fits inside the 94.6 mm bay height, so:
    - the case is now a plain prism, 151.4 x 94.6 x 235.6 mm, with a flat top
    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
    [dl380_cage_case.step, dl380_cage_case_body.step, dl380_cage_case_body.stl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]
2026-09-23 Fit the model to the actual fan: ARCTIC P9 PWM PST 92 mm
    Checked ARCTIC's own spec sheet (Spec_Sheet_P9_PWM_PST_EN.pdf, ACFAN00298A)
    rather than a reseller listing. Findings and what changed:
    - Mounting hole pattern is 82.5 mm square, so FAN_PATTERN was already right,
    and a 92 x 92 x 25 mm / 106 g frame fits the 151.4 x 94.6 mm rear face with
    29.7 mm at each side and 1.3 mm top and bottom.
    - The 4-pin plug housing is ~11 x 7 mm. The fan cable notch was 10 x 5 mm,
    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
    [dl380_cage_case.step, dl380_cage_case_body.step, dl380_cage_case_body.stl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]
2026-09-23 Move the fan inside and exhaust it through a printed honeycomb grille
    The fan no longer hangs off the back of the case; it sits inside the rear
    section, flat against the rear wall, and the exhaust leaves through a
    honeycomb grille recessed into the outer face.
    Consequences and changes:
    - A 92 mm frame is taller than the 87.8 mm cage bore, so the rear section now
    has to grow to swallow it. REAR_H is still derived, but from a new rule:
    INT_H_PLEN = max(INT_H, FAN_SIZE + 2*FAN_INNER_CLEAR), REAR_H = FLOOR_T +
    INT_H_PLEN + WALL. That yields 102.8 mm rear / 94.6 mm bay - an 8.2 mm step,
    not the 37 mm tower of v1. Give it a fan of 83.4 mm or less and REAR_H
    collapses back to BAY_H a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
    [dl380_cage_case.step, dl380_cage_case_body.step, dl380_cage_case_body.stl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]
2026-09-23 Route the SFF-8087 leads out of the back instead of the left side wall
    The two SFF-8087 -> SFF-8088 cables now exit through the rear wall, in two
    17 x 12 mm rounded slots at X = -60, Y = 33 and 50.
    - Each slot takes one ~12.5 x 8 mm SFF-8088 overmould with 4.5 x 4.0 mm of
    slack, and keeping them separate preserves each cable's own strain relief
    rather than having two cables sawing against each other in one hole.
    - They sit on the left because that is where the cabling already runs: the fan
    frame leaves a 26.9 mm chase down each side of the plenum.
    - Clearances verified: 6.54 mm from the slot corners to the grille pocket and
    7.20 mm outboard to the case edge, so no thin webs.
    - The o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
    [dl380_cage_case.step, dl380_cage_case_body.step, dl380_cage_case_body.stl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]
2026-09-23 Add a PicoPSU cradle in the plenum and a DC input jack in the rear wall
    The PicoPSU goes behind the backplane rather than floating loose, so it cannot
    slide back and short against the backplane PCB.
    mini-box picoPSU-120 measured 31 x 44 x 21 mm (1U), 57 g with its harness.
    Cradle, all on the plenum floor:
    - plinth 3 mm, so the board's solder side never touches the floor
    - side walls and a rear wall 24 mm tall, 0.8 mm clearance per side
    - a 6 mm front lip at the cradle mouth; the 3 mm that stands above the plinth is
    what stops the board sliding forward
    - the mouth sits 20 mm behind the backplane face, so even fully forward the
    board stops 21.6 mm short of it
    - two corner bosses with O4.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
    [dl380_cage_case.step, dl380_cage_case_body.step, dl380_cage_case_body.stl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]
2026-09-23 Update the README for the inside-fan / PicoPSU revision
    Documents the three design changes as a whole: the fan moved inside and now
    exhausts through a printed honeycomb grille, the SFF-8087 leads exit the back,
    and a PicoPSU cradle with its own rear DC jack was added.
    - new status table: three solids, their bboxes, the phantom-fit result, the
    watertightness of both STLs and the 33 STEP probes
    - plenum Z-map table so the front-to-back layout (boot space, cradle, cable
    routing, fan) is readable at a glance
    - new PicoPSU cradle section with the board dimensions, the cradle fit, the
    20 mm backplane gap and the reason the phantom check exists - including the
    left-boss bug it caught on fi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
2026-09-23 Widen the service opening so the fan can actually be installed
    Found while working out the assembly order: the service opening was 86 mm long
    (z 172..258) but the fan frame is 92 mm, so there was no way to lower the fan
    into the plenum flat. The numbers, checked before touching anything:
    opening width 109.8 mm vs 92 mm frame -> passes
    opening length 86.0 mm vs 92 mm frame -> TOO SHORT
    plenum bore 96.0 mm vs 92 mm frame -> 4 mm clearance, fine
    The only way in with the old opening was to feed the fan through at 45 degrees
    (z-extent 82.7 mm, y-extent 82.7 mm, both just fit) and rotate it flat inside -
    awkward, and it risks cracking the grille webs on the way past.
    SVC_Z1 m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
    [dl380_cage_case.step, dl380_cage_case_body.step, dl380_cage_case_body.stl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]
2026-09-23 Correct the fan drop-in geometry, and derive the opening from it
    The previous commit reached the right number by the wrong reasoning. The fan
    frame is 92 x 92 in the X-Y plane; its extent ALONG Z is only its 25 mm
    thickness. What the service opening has to clear is therefore 92 mm across and
    25 mm along, not 92 mm along. Redoing it properly:
    opening width 109.8 vs 92 (X) -> passes
    plenum bore 96.0 vs 92 (Y) -> 4 mm clearance
    opening length vs 25 (Z) -> the constraint is where, not how long
    The real constraint is that the fan can only descend BEHIND the PSU cradle
    (z > 233.4), so the usable window is z [235.4, SVC_Z1 - 25]:
    SVC_Z1 258 (the revision before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
    [dl380_cage_case.step, dl380_cage_case_body.step, dl380_cage_case_body.stl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]
2026-09-23 Add INSTALL.md - step-by-step assembly guide
    Written around the two questions that actually decide whether the thing goes
    together: which way the cage goes in, and what order the internals have to be
    fitted.
    - leads with the cage: it slides straight in from the front, backplane end
    first, 165 mm of travel onto the rear stop frame, 0.4 mm per side of
    clearance, no tilt or flex. Includes what to do when it fights you, which is
    'lift it out and scrape the sleeve', not 'push harder'.
    - makes the constrained order explicit and explains why: fan first because it
    ends up hard against the inside of the rear wall; cage next; cables before the
    cradle; PSU after the cables; lid last because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
2026-09-23 Round every outer edge (R1.4) so there is nothing sharp to catch a hand on
    Applied to the outside only, and applied to the BARE SHELL before anything is
    cut into it - filleting the finished body would also try to round the honeycomb
    webs, the 1.2 mm cell walls and every internal corner, and OCC will not survive
    that. Coplanar faces are merged with removeSplitter first, otherwise the seams
    between the two shell boxes get filleted into grooves.
    body R1.4 on all 18 outer edges, 896 mm3 of material off the shell
    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
    [dl380_cage_case.step, dl380_cage_case_body.step, dl380_cage_case_body.stl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]
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2026-09-23 Turn the lid into a drop-on housing that needs no screws
    The lid was a flat plate that only stayed on because six screws held it. It is
    now a skirted tray that slides straight down over the top of the case:
    - skirt 2.8 mm thick, 14 mm deep down the two sides and the back
    - the front skirt is only 8 mm, because the drive bay's roof is 8.2 mm below the
    top of the rear section and a full-depth skirt would land on it
    - 0.2 mm slip clearance, plus a 0.35 mm friction bead on three of the inner
    faces - a 0.15 mm light press fit, so it goes on by hand and stays put
    - located in X and Z by the skirt and in Y by resting on the top rim, so it
    cannot slide off in any direction. Only lifting remov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
    [dl380_cage_case.step, dl380_cage_case_body.step, dl380_cage_case_lid.step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]
2026-09-23 Document the drop-on housing lid
    - status table: lid is now a 157.4 x 17 x 122 skirted housing, lid retention is
    called out as needing no screws, and interference is no longer asserted zero -
    it is 283 mm3 of deliberate press fit, checked against what the bead band
    should account for
    - the lid section is rewritten around the skirt: depths, fit, what locates it,
    and how it comes off
    - a new "the fan cable is clear, three ways over" subsection giving all three
    clearances, since that was the specific worry
    - parameter table gains the SKIRT_* and LID_LIP_* numbers
    - new caveat: the press fit is the one dimension to trim to your own printer,
    with the exact recipe for too-tight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
2026-09-23 Give the fan its own housing: it slides in from the top, no screws
    The fan was dropped through the service opening and slid back 12.6 mm to seat,
    then held by four screws. It now has a proper housing:
    - it slides straight DOWN into a slot at Z 248..273 and seats on the plenum
    floor, which sets its height so the screw holes still line up if used
    - two guide rails, 42 mm up from the floor, 0.2 mm clearance per side, with a
    1.8 mm lead-in chamfer at the top so the frame finds the slot
    - the rear wall is behind it and two 16 mm front corner tabs stop it tipping
    forward
    - the lid grows two fins on its underside that reach down to y=97, 1 mm above
    the frame's top edge - that is the fifth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
    [dl380_cage_case.step, dl380_cage_case_body.step, dl380_cage_case_body.stl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]
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2026-09-24 Add a print kit: orientated STL + OBJ for a quoting service, with a manifest
    The service or marketplace wants STL/OBJ, so export_print_kit.py turns the built
    parts into files that can be quoted from directly.
    The part that matters is ORIENTATION. The CAD model uses Y as up (the body
    stands on Y=0) and every slicer uses Z as up, so the raw exports arrive wrong:
    the body lands lying on its back - a 281 mm tall object on the plate - and the
    lid lands upside down with its locating lip printed in mid air over the tray
    cavity, which needs support it must not have. Each part is therefore rotated
    until the face that belongs on the plate is at Z=0:
    body stands on its base rotate +90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
    [dl380-case_all-parts.obj, dl380-case_all-parts.stl, dl380-case_body.obj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]
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2026-09-24 Redesign plenum: compact 253.4mm depth, wider 200mm plenum, and transverse PicoPSU
    - Accommodate HP DL380 G6/G7 left-facing 10-pin power connector with 27.5mm lateral clearance
    - Widen plenum to 200mm internal (205.6mm outer) with stop frame notch
    - Rotate PicoPSU transversely (44mm X, 31mm Z) shifted to X=+40mm, leaving 117.2mm open floor on left for Wago 221 lever blocks
    - Shorten total enclosure depth from 281.4mm to 253.4mm (plenum 80mm deep) to print vertically on 256mm beds
    - Rotate lid 90 deg in print plate layout to fit 310.6x253.4mm within Bambu Lab 340x320mm bed
    - Re-probe 56 STEP features with verify_step.py (0 failures)
    - Update renders, export print kits, README.md, and INSTALL.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
    [dl380-case_all-parts.obj, dl380-case_all-parts.stl, dl380-case_body.obj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]
2026-09-24 feat: make enclosure uniform width with internal bottom slider rails
    - Unify outer width to 205.6 mm (200 mm inner) across both drive bay and plenum for unbroken, monolithic side walls.
    - Add internal bottom slider rails (14 mm tall) and ceiling ribs (5 mm tall) with 1.5 mm lead-in chamfers to guide the 145 mm HP drive cage.
    - Frame cage with 145.8 x 87.8 mm front aperture and solid 29.9 mm front cheeks to eliminate air bypass.
    - Provide 27.1 mm lateral wiring clearance on left side for 10-pin backplane power harness and Wago 221 blocks.
    - Transition cage mounting to 100% screwless slide-in against rear stop frame (0.0000 mm³ interference).
    - Update verify_step.py with 63 probes (0 failures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
    [dl380-case_all-parts.obj, dl380-case_all-parts.stl, dl380-case_body.obj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]
2026-09-24 Add fan front retaining rails, drive bay net motif, and Rp 600/g pricing
    [dl380-case_all-parts.obj, dl380-case_all-parts.stl, dl380-case_body.obj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]
2026-09-24 Fix fan front retaining rail placement to be symmetric on both sides
    [dl380-case_all-parts.obj, dl380-case_all-parts.stl, dl380-case_body.obj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]
2026-09-24 Remove underside fan fins from lid and add front center pull ring holder
    [dl380-case_all-parts.obj, dl380-case_all-parts.stl, dl380-case_lid.obj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]
2026-09-24 fix(cad): correct backplane orientation to upright with bottom-right power port
    - Update stop frame relief notch from top-left to lower-right (X = +68.9..72.9 mm, Y = 4.0..50.0 mm)
    - Restore full solid vertical pillar on the left stop frame
    - Shift transverse PicoPSU cradle to the left (X = -40.0 mm), opening a wide 117.2 mm right plenum floor for the 10-pin power harness and Wago blocks
    - Move DC jack to X = -70.0 mm (behind PicoPSU) and dual SAS cable egress slots to X = +70.0 mm
    - Add reference image docs/reference/cage-rear-upright-cable.png
    - Re-export all CAD models, print kit STLs/OBJs, and update documentation
    - Verified with FreeCAD: 71 probes, 0 failures (100% pass)
    [dl380-case_all-parts.obj, dl380-case_all-parts.stl, dl380-case_body.obj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]
2026-09-26 feat: implement Option A dual-chamber enclosure for DL380 cage and Enhance ENP-2320 Flex-ATX PSU
    [dl380_flex_case.step, dl380_flex_case_all-parts.stl, dl380_flex_case_body.step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]
2026-09-27 feat(dl380): migrate to Double-Decker basement with Flex-ATX PSU and 120mm rear fan
    [dl380_flex_case.step, dl380_flex_case_all-parts.stl, dl380_flex_case_body.step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]
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2026-09-27 feat(dl380): implement smooth-slide architecture with stud channels, runner ramps, and tab pockets
    [dl380_flex_case.step, dl380_flex_case_all-parts.stl, dl380_flex_case_body.step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]
2026-09-27 feat(fan-stand): replace side rails with dual-cradle fan stand (shelf cradle + lid top stand)
    [dl380_flex_case.step, dl380_flex_case_all-parts.stl, dl380_flex_case_body.step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]
2026-09-29 feat(cad): calibrate enclosure to digital caliper measurements
    - Calibrated front bezel socket: 180.0 x 86.0 x 11.5 mm with 17mm stop shoulders
    - Calibrated metal cage guide bay: 146.0 mm internal width (0.6mm clearance)
    - Added 4x longitudinal floor relief channels for 5.0 mm bottom shoulder pins
    - Sized rear tab clearance windows and mid-deck M3 locking bosses (35mm side margins)
    - Extended plenum with 15.75 mm clear air gap between 32mm rear tabs and 92mm fan
    - Re-routed 10-pin vertical power slot directly beneath right-side backplane socket
    - Widened lower wiring corridor to 96.5 mm next to Flex-ATX PSU
    - Passed all 34/34 physical & geometric verification audit tests
    - Re-rendered multi-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
    [dl380_flex_case.step, dl380_flex_case_all-parts.stl, dl380_flex_case_body.step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]
2026-09-30 feat(cad): modular 2-piece split with diamond mesh for Elegoo Centauri Carbon
    - Sliced chassis into 2 modular pieces: Front Disc Cage Case (Z=0-138mm) and Rear Backcase (Z=138-215mm)
    - Added large-pattern diamond mesh to Top Roof & Both Side Walls (saves ~100-125g filament)
    - Integrated 2.5mm tongue-and-groove interlocking lap-joint and 4x M3 fastener lugs
    - Added raised M3 mid-deck locking bosses for permanent rear cage tabs
    - Fully verified all 3 solids (Front, Back, Lid) are 100% closed and watertight
    - Passed 37/37 automated geometric and physical verification tests
    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
    [01_dl380_front_case.step, 01_dl380_front_case.stl, 02_dl380_back_case.step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]
2026-09-30 feat: implement Option A deep 4.5mm collar & tool-free cantilever snap-fit joint
    [01_dl380_front_case.step, 01_dl380_front_case.stl, 02_dl380_back_case.step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]
2026-09-30 feat: 100% screwless architecture with battery-door snap lid & zero screw holes
    [01_dl380_front_case.step, 01_dl380_front_case.stl, 02_dl380_back_case.step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]
2026-10-01 feat(print-package): calibrate for Elegoo Centauri Carbon 2 with ready-to-print 3MFs, recessed lid, and slicing skill
    [01_dl380_front_case.3mf, 01_dl380_front_case.step, 01_dl380_front_case.stl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]
2026-10-02 fix(print-quality): implement automated export pipeline resolving issues #1-#5 and #8
    - Issue #1: set filament_type=PETG and textured_plate_temp=70C in all 3MFs
    - Issue #2: bump wall_loops from 3 to 4 (1.6mm perimeter) for snap strength
    - Issue #3: set xy_hole_compensation = +0.10mm for dimensional accuracy
    - Issue #4: lower part cooling fan to 20-40% for optimal PETG layer welding
    - Issue #5: enable elefant_foot_compensation = 0.15mm for slide clearances
    - Issue #8: add reproducible export_print_package.py pipeline
    [01_dl380_front_case.3mf, 02_dl380_back_case.3mf, 03_dl380_service_lid.3mf]
2026-10-02 feat(calibration): add First Layer Bed Level Test kit for 256x256 Centauri Carbon 2
    [bed_level_test_5_squares_256x256.stl, bed_level_test_PETG_256x256.3mf, bed_level_test_PLA_256x256.3mf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]
2026-10-02 fix(dfam): add sacrificial breakaway fins and center divider to eliminate basement bridging sag
    [01_dl380_front_case.3mf, 01_dl380_front_case.step, 01_dl380_front_case.stl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]
2026-10-02 fix(dfam): shift basement fins left to X=12mm and add upper roof breakaway fins
    [01_dl380_front_case.3mf, 01_dl380_front_case.step, 01_dl380_front_case.stl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]
2026-10-02 Decrease support fins on first and second floors to sparse, clean layout
    [01_dl380_front_case.3mf, 01_dl380_front_case.step, 01_dl380_front_case.stl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]
2026-10-02 Align upper bridge supports directly over first floor supports creating unified vertical load columns
    [01_dl380_front_case.3mf, 01_dl380_front_case.step, 01_dl380_front_case.stl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]
2026-10-03 Relocate right support fin to X=120 on boss platform completely clear of power slot hole
    [01_dl380_front_case.3mf, 01_dl380_front_case.step, 01_dl380_front_case.stl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]
2026-10-03 Thicken support fins to 0.85mm double-perimeter walls for rigid standing stability
    [01_dl380_front_case.3mf, 01_dl380_front_case.step, 01_dl380_front_case.stl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]
2026-10-03 Add continuous bottom-to-end-top sacrificial support pillar passing through 1st floor cable hole
    [01_dl380_front_case.3mf, 01_dl380_front_case.step, 01_dl380_front_case.stl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]
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2026-10-03 fix(dl380): calibrate rear PSU C14 port, 40mm fan bore, and #6-32 mounting holes from caliper measurements
    [01_dl380_front_case.3mf, 01_dl380_front_case.step, 01_dl380_front_case.stl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]
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2026-10-03 fix(support): replace thin 2D planar breakaway fins with 3D corrugated cubic support columns
    [01_dl380_front_case.3mf, 01_dl380_front_case.step, 01_dl380_front_case.stl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]
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2026-10-03 feat: implement 4-piece modular enclosure with internal corner snap latches
    - Separates enclosure horizontally along mid-deck into 4 quadrants plus service lid (01A, 01B, 02A, 02B, 03).
    - 100% Support-Free Printing for 01A, 01B, 02A, and 03; minimal build-plate support (~8g) for 02B latch arms.
    - Grounded internal vertical snap pillars with 45-degree self-supporting retention teeth ensure flush outer side walls.
    - Side-wall alignment tongue-and-groove joint absorbs lateral shear and drive vibration.
    - All FreeCAD solid models verified watertight manifold closure (isClosed: True).
    - Calibrated and verified with Elegoo Slicer CLI on Elegoo Centauri Carbon 2: 0 errors, 0 warnings across all 5 p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
    [01A_dl380_lower_front.3mf, 01A_lower_front.step, 01A_lower_front_bed.stl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]
2026-10-03 fix(02B): replace buggy hex peg fan grille with 45° self-supporting diamond mesh
    - Replaced inverted hex boolean that created 80 freestanding floating pegs with a clean 45° self-supporting diamond mesh.
    - Every strut is angled at 45° to the build plate, eliminating bridging, sagging, and stringing.
    - Reduces Part 02B filament from 307.7g to 286.8g and print time to 22h 47m.
    - Total 4-piece enclosure filament reduced to 923.6g.
    - Verified in FreeCAD with solid watertight manifold (isClosed: True).
    - Sliced and verified in Elegoo Slicer CLI for ECC2: 0 errors, 0 warnings.
    - Regenerated STEP models, bed STLs, calibrated 3MFs, documentation, and DL380_4Piece_Print_Package.zip.
    [01A_dl380_lower_front.3mf, 01A_lower_front.step, 01B_dl380_upper_front.3mf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]
2026-10-03 feat(02A,02B): enlarge snap latches to 20mm with 2mm tooth and 2.2mm beam
    [01A_dl380_lower_front.3mf, 01A_lower_front.step, 01B_dl380_upper_front.3mf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]
2026-10-03 fix(02B): center internal chamber void at X_CAGE_0 for symmetric 20mm walls
    [01A_dl380_lower_front.3mf, 01A_lower_front.step, 01B_dl380_upper_front.3mf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]
2026-10-03 feat(02A): reinforce PSU right guide rail to 3.8mm with triangular base gusset
    [01A_dl380_lower_front.3mf, 01A_lower_front.step, 01B_dl380_upper_front.3mf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]
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2026-10-03 fix(01A,02A): shift PSU bay +4.2mm to eliminate collision with snap tower
    [01A_dl380_lower_front.3mf, 01A_lower_front.step, 01A_lower_front_bed.stl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]
